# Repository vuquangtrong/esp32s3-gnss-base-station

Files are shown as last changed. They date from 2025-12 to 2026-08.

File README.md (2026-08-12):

# RTK GNSS Base Station using ESP32-S3 and Ublox ZED-F9P

Design and build a RTK GNSS Base Station to provide precise positioning service, which sends RTCM messages over a self-hosted NTRIP web server or an external Radio module, supports micro SD Card storage for post-processing purposes.

This project is developed on top of [ESP32-S3-WROOM-1-N16R8](https://documentation.espressif.com/esp32-s3-wroom-1_wroom-1u_datasheet_en.pdf), with below specifications:

- Xtensa® dual-core 32-bit LX7 microprocessor with single precision FPU, up to 240 MHz
- 384 KB ROM
- 512 KB SRAM + 16 KB SRAM in RTC
- Embedded 8 MB PSRAM (Octal SPI), up to 80 MHz
- Integrated 16 MB Flash (Quad SPI), up to 80 MHz
- 2.4 GHz Wi-Fi (802.11b/g/n, STA/AP/STA+AP, 150 Mbps) and Bluetooth 5 (BLE, Mesh, 2 Mbps)
- SPI, LCD interface, Camera interface, UART, I2C, I2S, remote control, pulse counter, LED PWM, full-speed USB 2.0 OTG, USB Serial/JTAG controller, MCPWM, SD/MMC host controller, GDMA, TWAI® controller (compatible with ISO 11898-1), ADC, touch sensor,temperature sensor, timers and watchdogs
- 36 GPIOs

## Hardware

### Design Tools

Install **KiCad**:

```sh
sudo add-apt-repository ppa:kicad/kicad-9.0-releases
sudo apt update
sudo apt install kicad
```

Extensions:

- Parts from Espressif: <https://github.com/espressif/kicad-libraries>
- Parts from JLCPCB: <https://github.com/CDFER/JLCPCB-Kicad-Library>
- PCB Export to JLCPCB: <https://github.com/Bouni/kicad-jlcpcb-tools>
- PCB RF tools: <https://github.com/easyw/RF-tools-KiCAD>

Parts:

- JLCPCB Parts: <https://jlcpcb.com/parts/> which mainly is from LCSC Parts: <https://www.lcsc.com/>

  - Search for **Stock Type = In Stock** and **Parts Type = Basic | Promotional Extended** and **PCBA Type = Economic**

  - Use `easyeda2kicad` to download symbols, footprints and 3D models from LCSC to KiCAD:

    <details>

    <https://github.com/enduity/easyeda2kicad>>

    Install:

    ``` sh
    cd hardware
    git clone https://github.com/enduity/easyeda2kicad
    cd easyeda2kicad
    python3 -m venv .venv
    source .venv/bin/activate
    pip install .
    ```

    Go back to the hardware project folder, create `libs` folder:

    ```sh
    cd ..
    mkdir -p libs
    ```

    Then download parts from LCSC, for example, ESP32-S3-WROOM-1-N16R8 has LCSCID=C2913202:

    ```sh esp32-s3-gnss-base-station/hardware (.venv)
    easyeda2kicad --lcsc_id C2913202 --full --output ./libs/LCSC --project-relative
    ```

    Add the LCSC libs into KiCAD projects:

    - Goto `Preferences` > `Manage Symbol Libraries`, in Project Specific Libs, add `${KIPRJMOD}/libs/LCSC.kicad_sym`
    - Goto `Preferences` > `Manage Footprint Libraries`, in Project Specific Libs, add `${KIPRJMOD}/libs/LCSC.pretty`

    </details>

### Schematic

**Components**:

| Part | Link |
| --- | --- |
| Espressif WiFi Module ESP32-S3-WROOM-1-N16R8 | <https://jlcpcb.com/partdetail/3198300-ESP32_S3_WROOM_1N16R8/C2913202> |
| U-blox GNSS Receiver ZED-F9P-04B | <https://jlcpcb.com/partdetail/UBLOX-ZED_F9P04B/C5120257> |
| ShouHan Female Micro-B Connector MicroQTJ | <https://jlcpcb.com/partdetail/SHOUHAN-MicroQTJ/C404968> |
| SOFNG MicroSD Card Push-Push Connector TF001B | <https://jlcpcb.com/partdetail/SOFNG-TF001B/C125617> |
| XKB 125V 3A SPDT Slide Switch SS-12D10L5 | <https://jlcpcb.com/partdetail/XKBConnection-SS12D10L5/C319012> |
| SILICON LABS 3.3V 20mA 1Mbps USB 2.0 Transceiver CP2102-GMR | <https://jlcpcb.com/partdetail/SKYWORKS_SILICONLABS-CP2102GMR/C6568> |
| TOPPOWER 4.2V 450mA 1-Cell Lithium Battery Charger TP4054-42-SOT25R | <https://jlcpcb.com/partdetail/33539-TP4054_42SOT25R/C32574> |
| Silergy Corp 2.7-5.5V 2A Adjustable Buck DC Converter SY8089AAAC | <https://jlcpcb.com/partdetail/SilergyCorp-SY8089AAAC/C78988> |
| Hongjiacheng 2-NPN SOT-363 Bipolar MMDT3904 | <https://jlcpcb.com/partdetail/hongjiacheng-MMDT3904/C41375125> |
| JST 1x2P 2mm Connector B2B-PH-K-S(LF)(SN) | <https://jlcpcb.com/partdetail/JST-B2B_PH_K_S_LF_SN/C131337> |
| UNI-ROYAL(Uniroyal Elec) 100mW 33Ω 75V 0603 SMD 0603WAF330JT5E | <https://jlcpcb.com/partdetail/23867-0603WAF330JT5E/C23140> |
| UNI-ROYAL(Uniroyal Elec) 100mW 1kΩ 75V 0603 SMD 0603WAF1001T5E | <https://jlcpcb.com/partdetail/21904-0603WAF1001T5E/C21190> |
| UNI-ROYAL(Uniroyal Elec) 100mW 2.2kΩ 75V 0603 SMD 0603WAF2201T5E | <https://jlcpcb.com/partdetail/4597-0603WAF2201T5E/C4190> |
| UNI-ROYAL(Uniroyal Elec) 100mW 10kΩ 75V 0603 SMD 0603WAF1002T5E | <https://jlcpcb.com/partdetail/26547-0603WAF1002T5E/C25804> |
| UNI-ROYAL(Uniroyal Elec) 100mW 150kΩ 75V 0603 SMD 0603WAF1503T5E | <https://jlcpcb.com/partdetail/23534-0603WAF1503T5E/C22807> |
| UNI-ROYAL(Uniroyal Elec) 100mW 680kΩ 75V 0603 SMD 0603WAF6803T5E | <https://jlcpcb.com/partdetail/26565-0603WAF6803T5E/C25822> |
| Samsung Electro-Mechanics 100nF 16V X7R ±10% 0402 Ceramic Capacitors CL05B104KO5NNNC | <https://jlcpcb.com/partdetail/1877-CL05B104KO5NNNC/C1525> |
| Samsung Electro-Mechanics 10uF 25V X5R ±20% 0603 Ceramic Capacitors CL10A106MA8NRNC  | <https://jlcpcb.com/partdetail/97651-CL10A106MA8NRNC/C96446> |
| Samsung Electro-Mechanics 22uF 25V X5R ±20% 0805 Ceramic Capacitors CL21A226MAQNNNE  | <https://jlcpcb.com/partdetail/46786-CL21A226MAQNNNE/C45783> |
| Samsung Electro-Mechanics 47pF 50V C0G ±5% 0603 Ceramic Capacitors CL10C470JB8NNNC | <https://jlcpcb.com/partdetail/2023-CL10C470JB8NNNC/C1671> |
| Hubei KENTO Elec 2.4V 20mA 300mcd 40mW 645nm Red Water Clear 0603 LED | <https://jlcpcb.com/partdetail/Hubei_KENTOElec-KT0603R/C2286> |
| Sunlord 2.2uH 2A 52mΩ ±20% SMD 4x4mm Power Inductors SWPA4026S2R2MT | <https://jlcpcb.com/partdetail/Sunlord-SWPA4026S2R2MT/C96891> |
| Murata Electronics 110mA 120nH 2.66Ω ±5% 0402 Power Inductors LQW15ANR12J00D | <https://jlcpcb.com/partdetail/MurataElectronics-LQW15ANR12J00D/C113123> |
| Q&J CR1220 SMD Button And Strip Battery Connector CR1220-2 | <https://jlcpcb.com/partdetail/QJ-CR12202/C70381> |
| BAT WIRELESS 50Ω 6GHz SMB Female Connectors BWSMB-KE | <https://jlcpcb.com/partdetail/BATWIRELESS-BWSMBKE/C5250063> |

**Schematic**

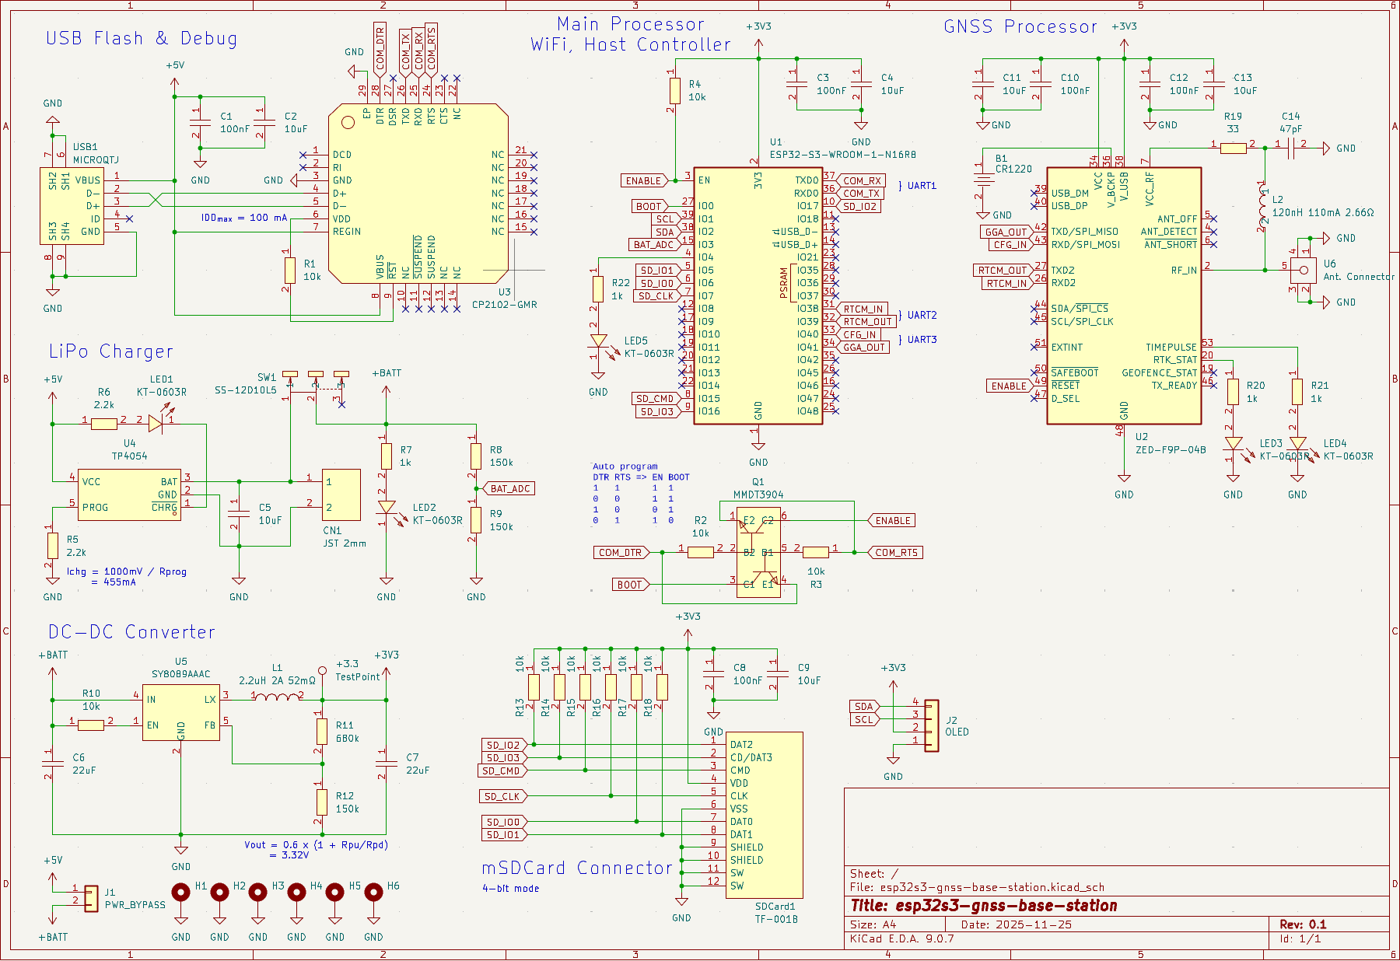
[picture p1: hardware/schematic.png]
Schematic


### PCB Layout

Layers:

- Front Copper: Signal
- Inner 1: GND
- Inner 2: GND
- Back Copper: Signal

RF Path:

- In ZED-F9P Integration manual, it mentions that RF input should ensure RF trace is tuned for 50 Ω to ensure adequate bandwidth and power matching
- Board will be made by JLCPCB, refer their guidance at <https://jlcpcb.com/help/article/User-Guide-to-the-JLCPCB-Impedance-Calculator> to get the trace width, details in [RF Impedance Calculator](hardware/impedance_calculator.png)

PCB Layout:

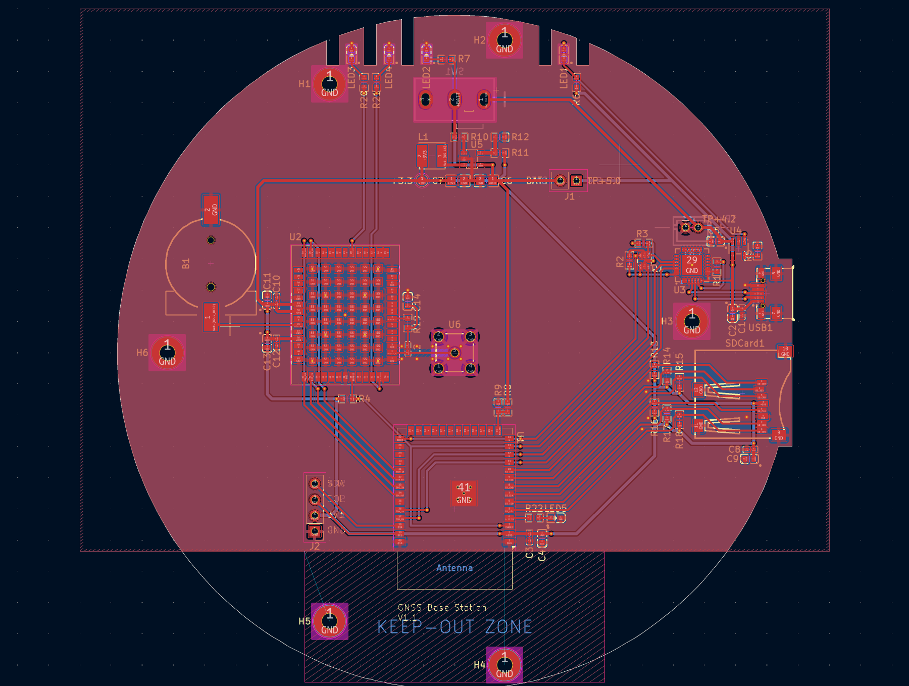
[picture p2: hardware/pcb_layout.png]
Layout


The rendered images:

<div style="display: flex; gap: 16px;">
  <div style="flex: 1;">
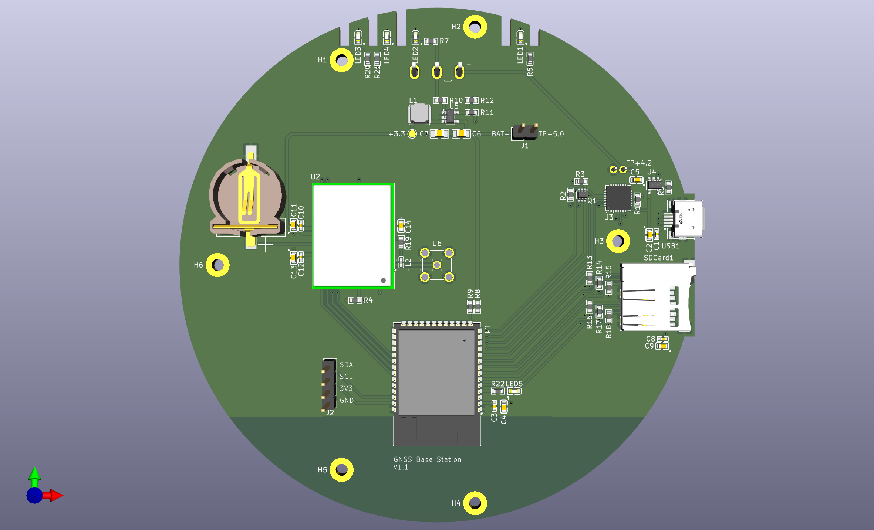
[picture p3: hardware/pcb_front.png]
    
  </div>
  <div style="flex: 1;">
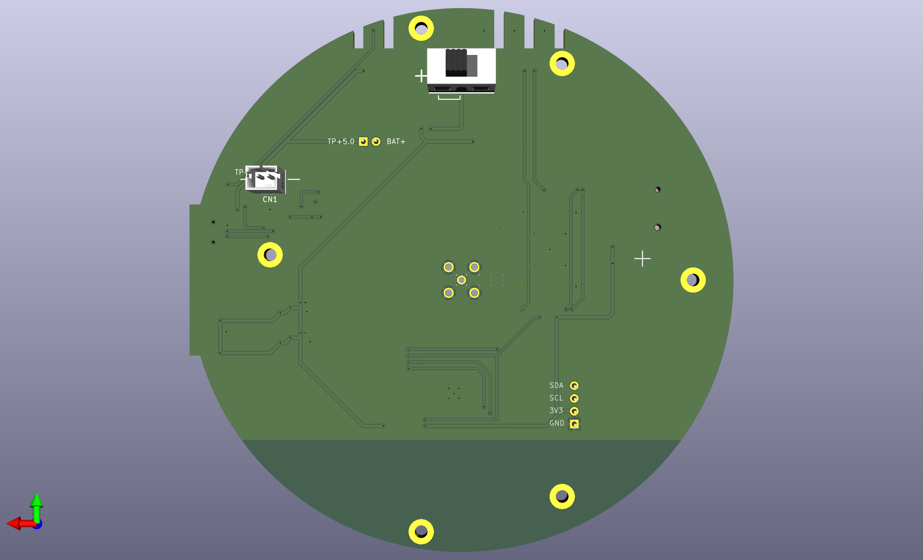
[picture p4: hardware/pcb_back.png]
    
  </div>
</div>

The final board:

<div style="display: flex; gap: 16px;">
  <div style="flex: 1;">
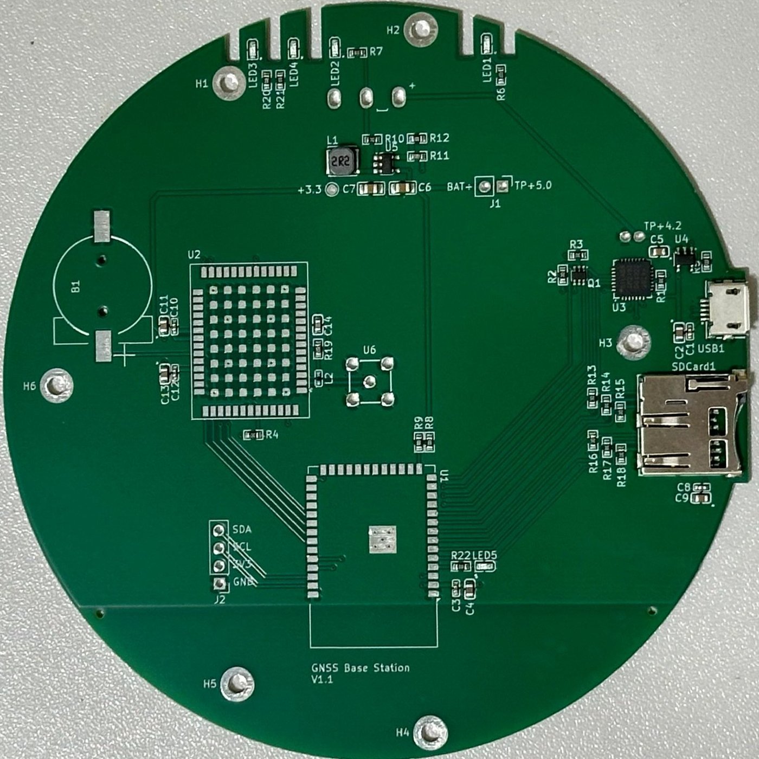
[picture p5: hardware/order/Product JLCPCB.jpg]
    
  </div>
  <div style="flex: 1;">
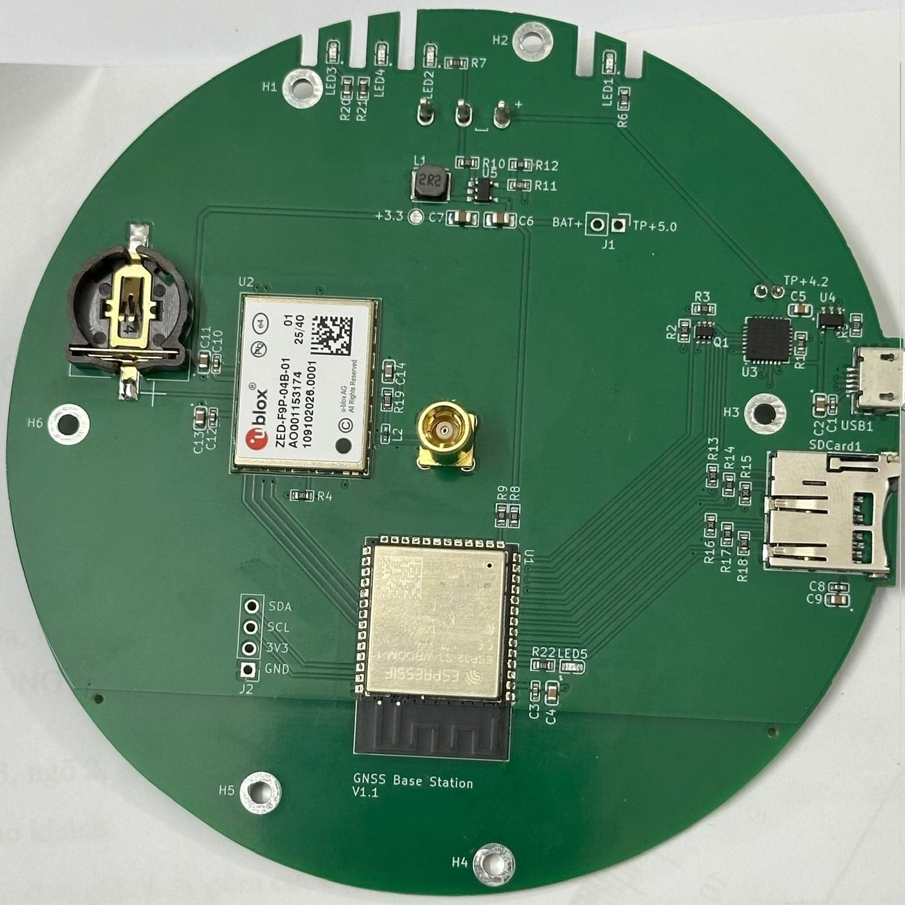
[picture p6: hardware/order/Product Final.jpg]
    
  </div>
</div>

------------------------------------------------------------

## Firmware

### Development Tools

- IDE: Visual Studio Code + ESP-IDF Extenstion
- Framework: ESP-IDF for ESP32-S3

### ESP-IDF

Install EIM:

``` sh
echo "deb [trusted=yes] https://dl.espressif.com/dl/eim/apt/ stable main" | sudo tee /etc/apt/sources.list.d/espressif.list
sudo apt update
sudo apt install eim
```

Install ESP-IDF SDK from EIM:

- Install latest STABLE version, at the moment, it is 6.0.2. The online document for ESP32-S3 is at <https://docs.espressif.com/projects/esp-idf/en/v6.0.2/esp32s3/index.html>
- Use default settings

Add OpenOCD udev rules:

``` sh
find ~/.espressif -type f -name "*.rules" -exec sudo cp -v {} /etc/udev/rules.d/ \;
sudo udevadm control --reload-rules
sudo udevadm trigger
```

### SDK Config

``` ini
CONFIG_IDF_TARGET="esp32s3"
CONFIG_BOOTLOADER_LOG_LEVEL_NONE=y
CONFIG_ESPTOOLPY_FLASHMODE_QIO=y
CONFIG_ESPTOOLPY_FLASHSIZE_16MB=y
CONFIG_COMPILER_OPTIMIZATION_PERF=y
CONFIG_ESP_DEFAULT_CPU_FREQ_MHZ_240=y
CONFIG_ESP32S3_INSTRUCTION_CACHE_32KB=y
CONFIG_ESP32S3_INSTRUCTION_CACHE_LINE_32B=y
CONFIG_ESP32S3_DATA_CACHE_64KB=y
CONFIG_ESP32S3_DATA_CACHE_LINE_64B=y
CONFIG_FREERTOS_GENERATE_RUN_TIME_STATS=y
CONFIG_LOG_DYNAMIC_LEVEL_CONTROL=n
CONFIG_LOG_TAG_LEVEL_IMPL_NONE=y
```

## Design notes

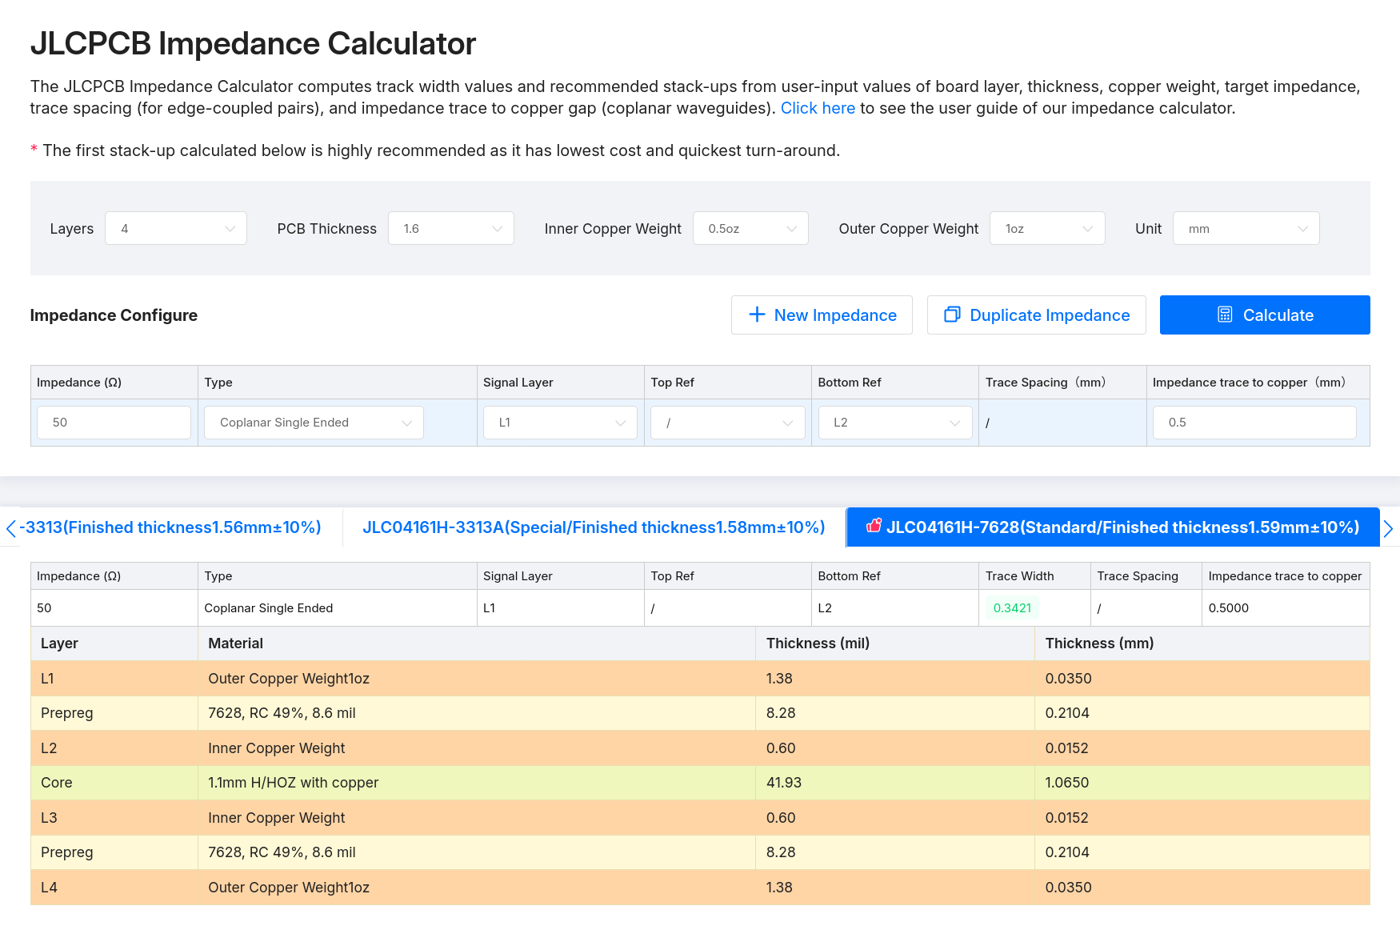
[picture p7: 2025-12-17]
hardware/impedance_calculator.png

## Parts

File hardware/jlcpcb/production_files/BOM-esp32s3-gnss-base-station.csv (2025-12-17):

Comment | Designator | Footprint | LCSC | Quantity
100nF | C1,C10,C12,C3,C8 | C0402 | C1525 | 5
10k | R1,R10,R13,R14,R15,R16,R17,R18,R2,R3,R4 | R0603 | C25804 | 11
10uF | C11,C13,C2,C4,C5,C9 | C0603 | C96446 | 6
120nH 110mA 2.66Ω | L2 | L0402 | C113123 | 1
150k | R12,R8,R9 | R0603 | C22807 | 3
1k | R20,R21,R22,R7 | R0603 | C21190 | 4
2.2k | R5,R6 | R0603 | C4190 | 2
2.2uH 2A 52mΩ | L1 | IND-SMD_L4.0-W4.0 | C96891 | 1
22uF | C6,C7 | C0805 | C45783 | 2
33 | R19 | R0603 | C23140 | 1
47pF | C14 | C0603 | C1671 | 1
680k | R11 | R0603 | C25822 | 1
CP2102-GMR | U3 | WQFN-28_L5.0-W5.0-P0.50-BL-EP3.2 | C6568 | 1
KT-0603R | LED1,LED2,LED3,LED4,LED5 | LED0603-RD | C2286 | 5
MICROQTJ | USB1 | MICRO-USB-SMD_MICROQTJ-5P | C404968 | 1
MMDT3904 | Q1 | SOT-363_L2.0-W1.3-P0.65-LS2.1-BR | C41375125 | 1
SY8089AAAC | U5 | SOT-23-5_L3.0-W1.7-P0.95-LS2.8-BR | C78988 | 1
TF-001B | SDCard1 | TF-SMD_TF-001B | C125617 | 1
TP4054 | U4 | SOT-23-5_L3.0-W1.7-P0.95-LS2.8-BL | C32574 | 1

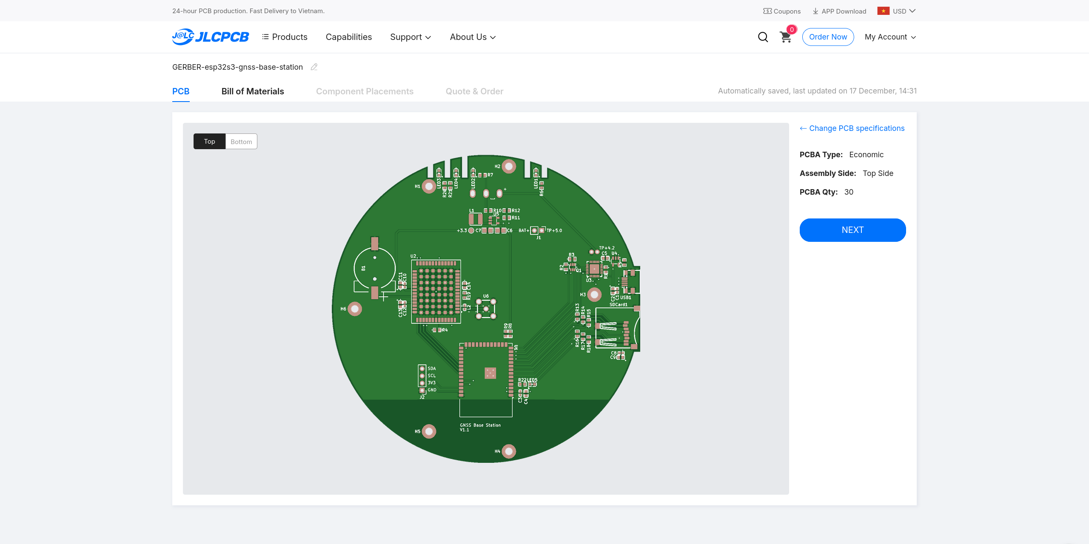
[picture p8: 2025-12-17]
hardware/order/Screenshot 2025-12-17 at 14-31-33 PCB Preview - JLCPCB.png

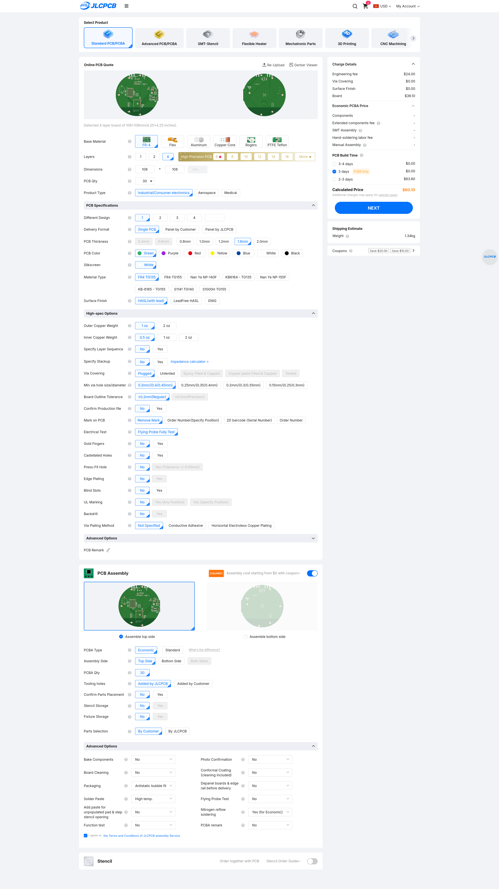
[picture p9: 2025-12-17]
hardware/order/Screenshot 2025-12-17 at 14-31-19 PCB Instant Quote - JLCPCB.png

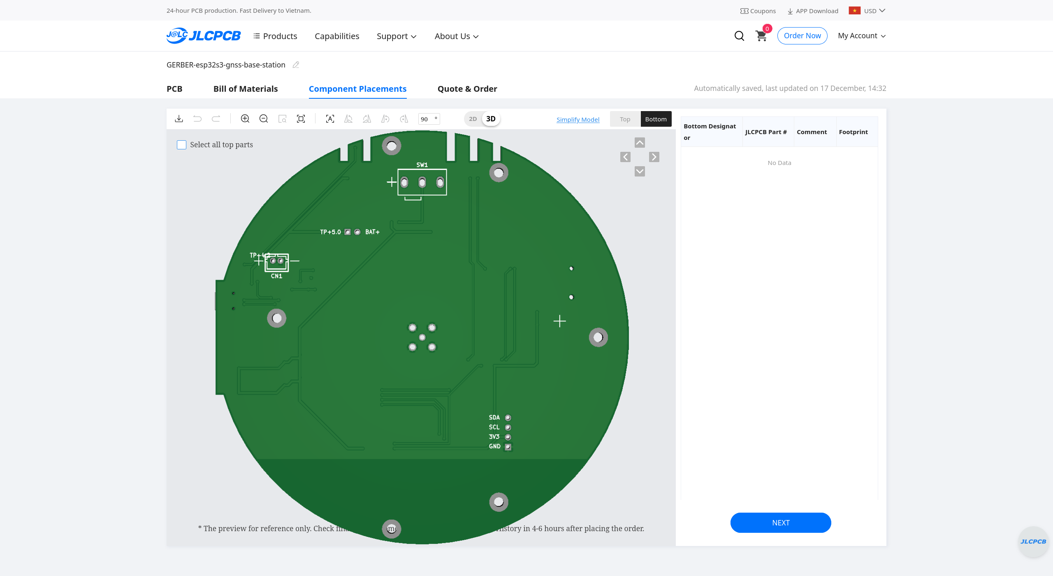
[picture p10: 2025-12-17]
hardware/order/Screenshot 2025-12-17 at 14-34-23 CPL Preview - JLCPCB.png

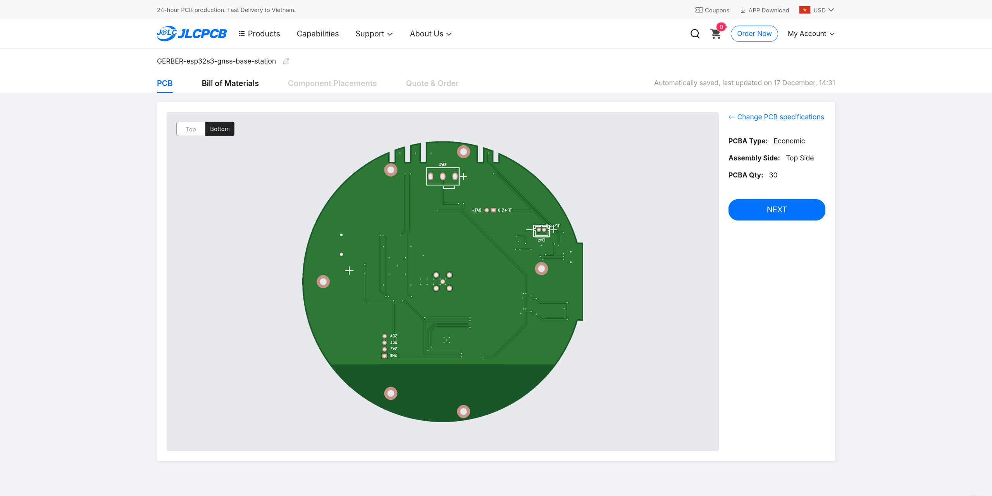
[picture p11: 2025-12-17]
hardware/order/Screenshot 2025-12-17 at 14-31-39 PCB Preview - JLCPCB.png

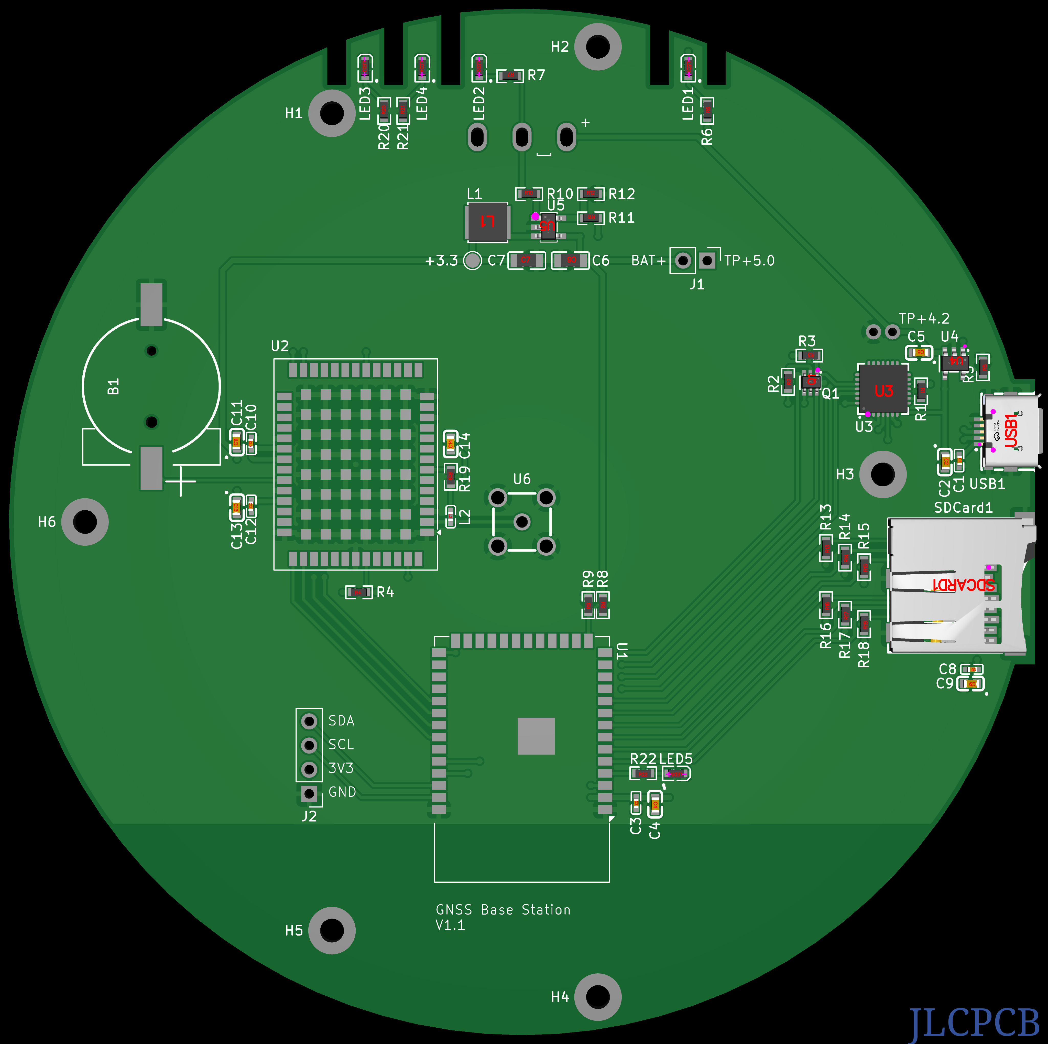
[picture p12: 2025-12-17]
hardware/order/Screenshot 2025-12-17 at 14-33-52 CPL Preview - JLCPCB.jpeg

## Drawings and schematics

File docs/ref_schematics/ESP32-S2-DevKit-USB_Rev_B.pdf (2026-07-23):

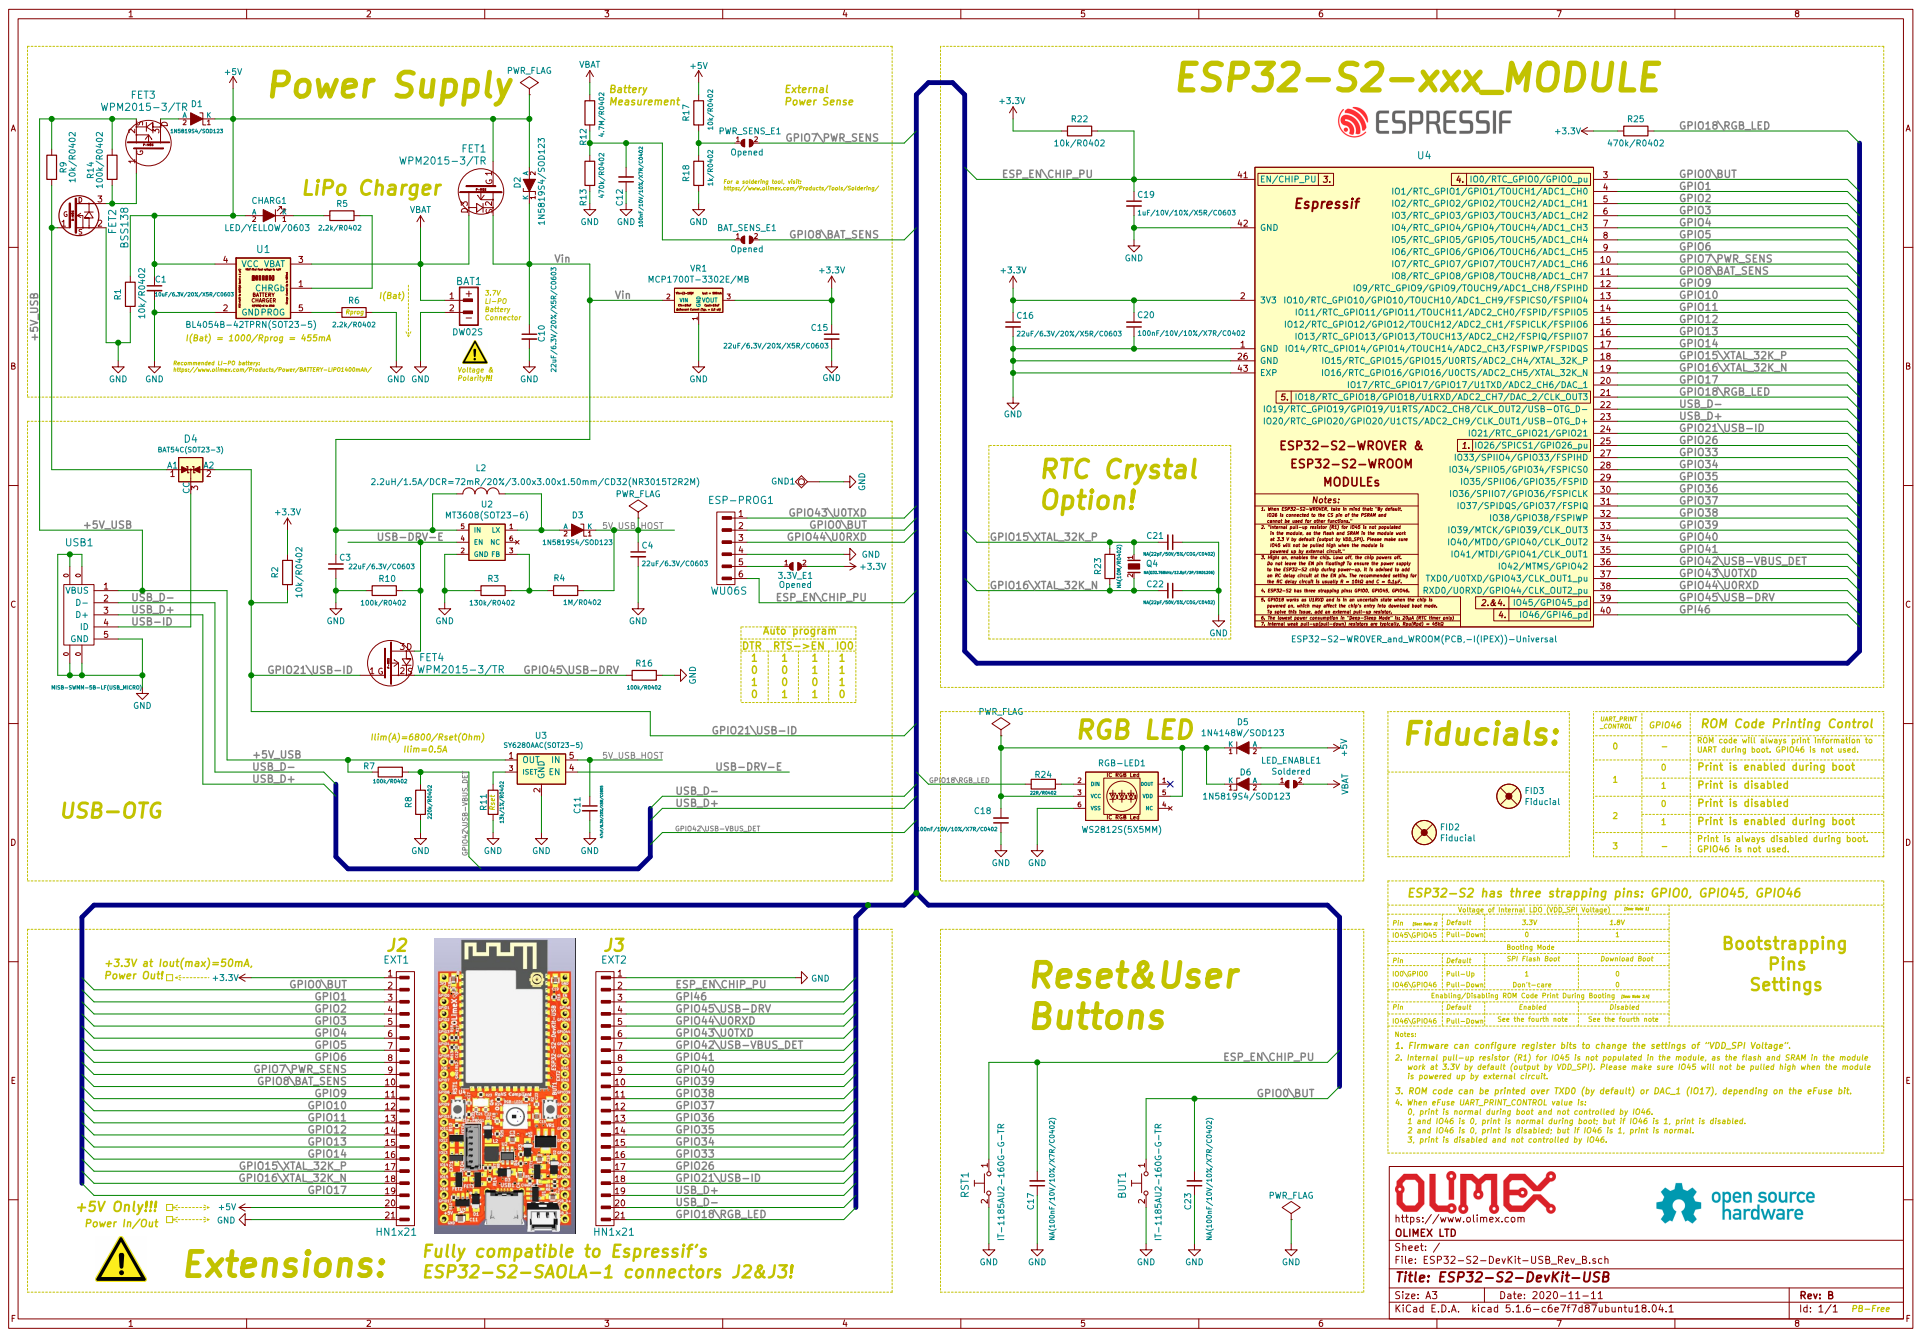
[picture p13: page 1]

Booting Mode LiPo Charger

For a soldering tool, visit: https://www.olimex.com/Products/Tools/Soldering/

1 2 Q4 R23 NA(Q32.768kHz/12.5pF/2P/SMD1206) NA(10M/R0402) Charge Current Up to 800mA R(PROG)=2 to 10k VBAT final float voltage to 4.2V VCC=4.5V to 6.5V(at least a 1 F) BATTERY CHARGER CHRGb 1 GND 2 VBAT 3 VCC 4 PROG 5 U1

to the ESP32-S2 chip during power-up, it is advised to add GND 1

Recommended LI-PO battery: https://www.olimex.com/Products/Power/BATTERY-LIPO1400mAh/

4. ESP32-S2 has three strapping pins: GPIO0, GPIO45, GPIO46. 5.

GPIO21\USB-ID GPIO41 GPIO21\USB-ID GPIO40

cannot be used for other functions." Do not leave the EN pin floating! To ensure the power supply ESP32-S2-WROOM

IO45 will not be pulled high when the module is MODULEs

IO26 is connected to the CS pin of the PSRAM and

in the module, as the flash and SRAM in the module work
5. GPIO18 works as U1RXD and is in an uncertain state when the chip is 6. The lowest power consumption in "Deep-Sleep Mode" is: 20A (RTC timer only) 7. Internal weak pull-up(pull-down) resistors are typically, Rpu(Rpd) = 45k an RC delay circuit at the EN pin. The recommended setting for at 3.3 V by default (output by VDD_SPI). Please make sure

powered on, which may affect the chips entry into download boot mode. powered up by external circuit."
3. High: on, enables the chip. Low: off, the chip powers off.

the RC delay circuit is usually R = 10k and C = 0.1F. To solve this issue, add an external pull-up resistor.

See the fourth note RGB LED

Ilim(A)=6800/Rset(Ohm)
- Fully compatible to Espressif's
Ilim=0.5A

0 Print is disabled Print is disabled

is powered up by external circuit. 1. Firmware can configure register bits to change the settings of VDD_SPI Voltage. Notes: ESP32-S2 has three strapping pins: GPIO0, GPIO45, GPIO46

3, print is disabled and not controlled by IO46. 3. ROM code can be printed over TXD0 (by default) or DAC_1 (IO17), depending on the eFuse bit. 2. Internal pull-up resistor (R1) for IO45 is not populated in the module, as the flash and SRAM in the module
work at 3.3V by default (output by VDD_SPI). Please make sure IO45 will not be pulled high when the module

0, print is normal during boot and not controlled by IO46.
1 and IO46 is 0, print is normal during boot; but if IO46 is 1, print is disabled.
2 and IO46 is 0, print is disabled; but if IO46 is 1, print is normal.

1 2BUT1 IT-1185AU2-160G-G-TR GND GND

File: ESP32-S2-DevKit-USB_Rev_B.sch Sheet: / OLIMEX LTD

Id: 1/1 Title: ESP32-S2-DevKit-USB

Rev: B | F Date: 2020-11-11 KiCad E.D.A. kicad 5.1.6-c6e7f7d87ubuntu18.04.1 Size: A3

PB-Free

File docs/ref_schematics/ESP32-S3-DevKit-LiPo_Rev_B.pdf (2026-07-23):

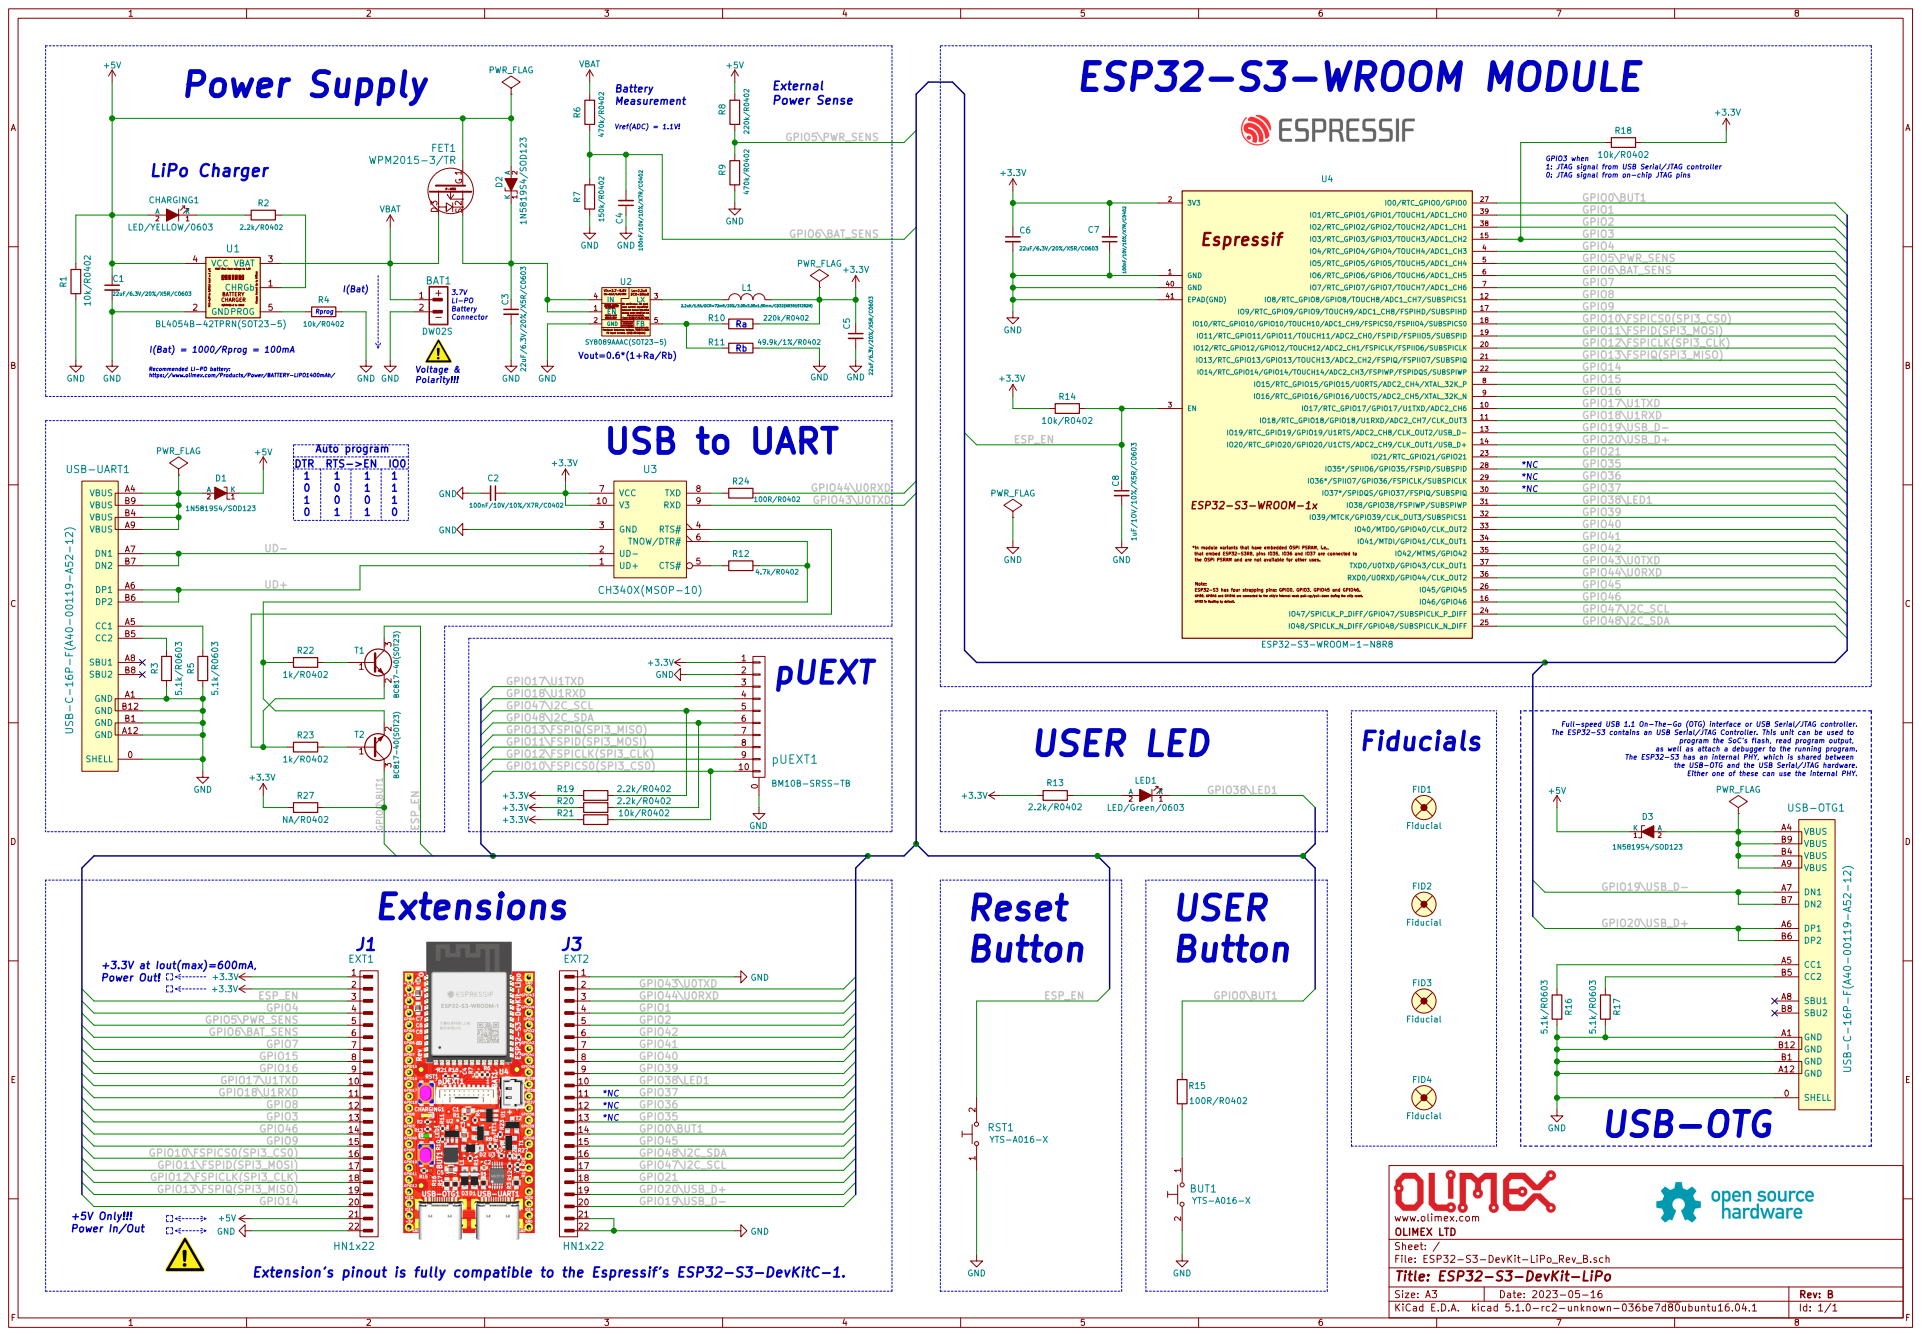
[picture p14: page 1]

External
Power Sense
the OSPI PSRAM and are not available for other uses. GND 1

10k/R0402 GPIO3 when 1: JTAG signal from USB Serial/JTAG controller 0: JTAG signal from on-chip JTAG pins

Full-speed USB 1.1 On-The-Go (OTG) interface or USB Serial/JTAG controller. The ESP32-S3 contains an USB Serial/JTAG Controller. This unit can be used to program the SoCs flash, read program output, as well as attach a debugger to the running program. The ESP32-S3 has an internal PHY, which is shared between the USB-OTG and the USB Serial/JTAG hardware. Either one of these can use the internal PHY. GPIO6\BAT_SENS

load current capability! Lx=2.2uH

Do not float. Enable control. FB Input Current, I(FB)=50nA(max) Feedback Reference Voltage, V(REF)=0.6V

*In module variants that have embedded OSPI PSRAM, i.e., ESP32-S3 has four strapping pins: GPIO0, GPIO3, GPIO45 and GPIO46. ESP32-S3-WROOM-1x

that embed ESP32-S3R8, pins IO35, IO36 and IO37 are connected to

GPIO0, GPIO45 and GPIO46 are connected to the chips internal weak pull-up/pull-down during the chip reset. GPIO3 is floating by default. Note:

9EXT1 HN1x22 Extension's pinout is fully compatible to the Espressif's ESP32-S3-DevKitC-1.
+3.3V GND
ESP_EN GPIO4 GPIO5\PWR_SENS

www.olimex.com
File: ESP32-S3-DevKit-LiPo_Rev_B.sch Sheet: / OLIMEX LTD

Id: 1/1 Title: ESP32-S3-DevKit-LiPo

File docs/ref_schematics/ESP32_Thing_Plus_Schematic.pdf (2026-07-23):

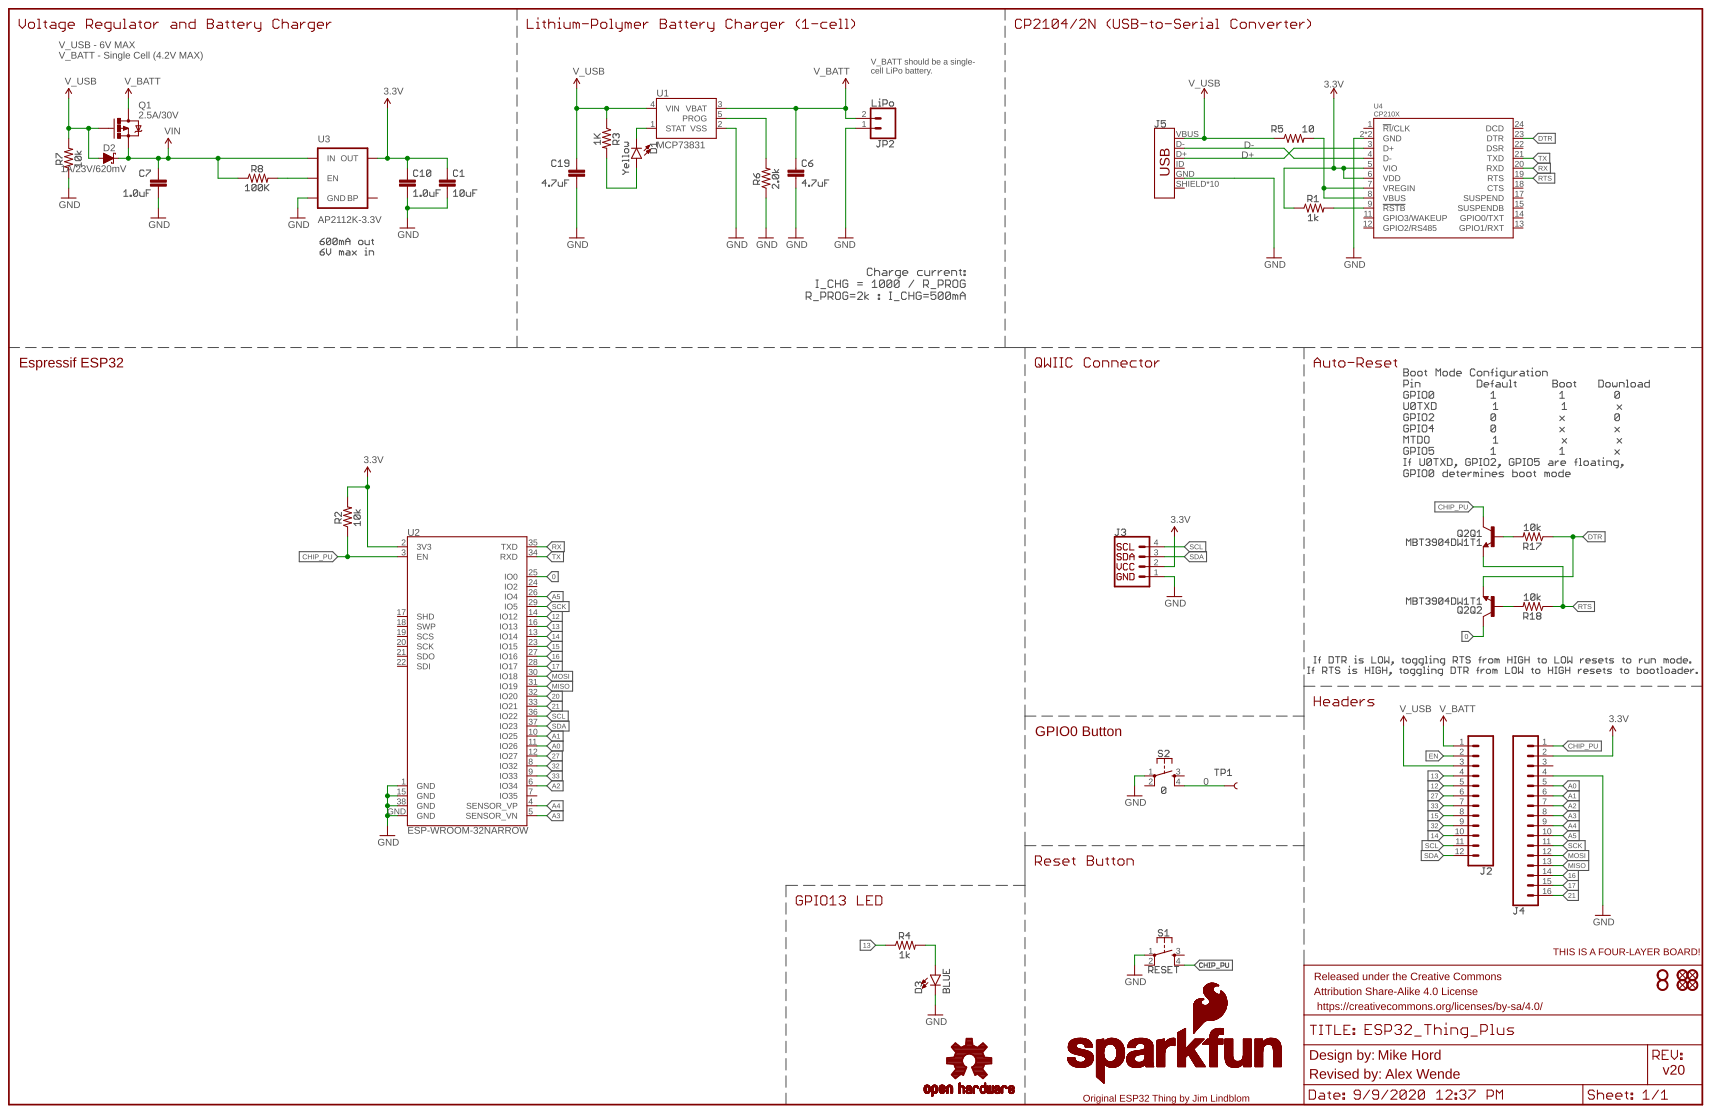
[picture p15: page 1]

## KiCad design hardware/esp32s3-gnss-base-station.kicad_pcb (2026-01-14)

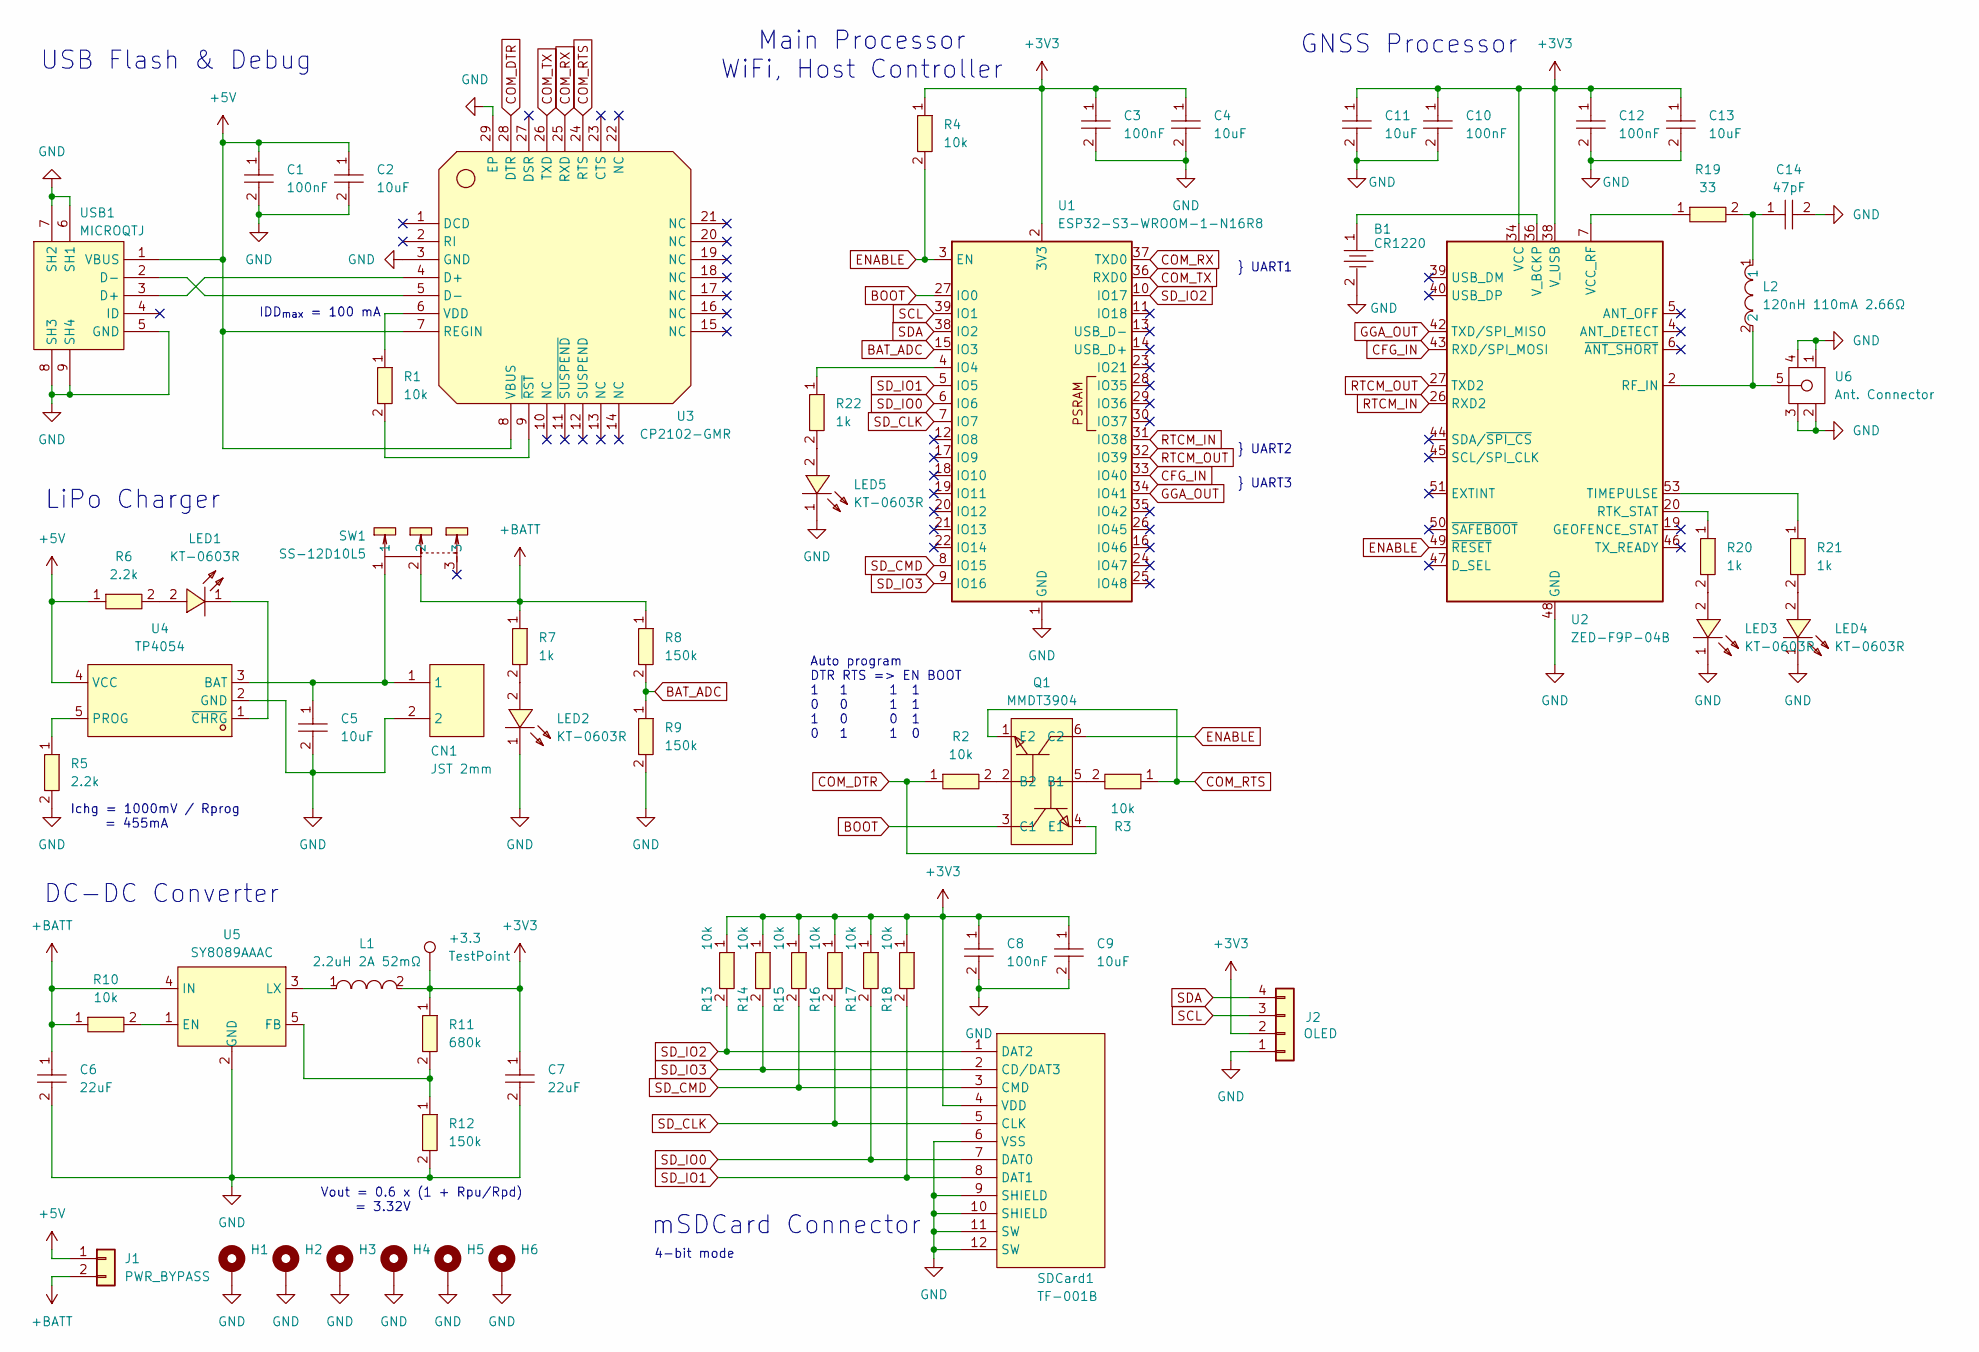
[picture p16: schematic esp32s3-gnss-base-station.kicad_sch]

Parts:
+3.3: TestPoint; TestPoint_Pad_D1.5mm
B1: CR1220; BAT-SMD_CR1220-2; LCSC Part C70381
C1, C3, C8, C10, C12: 100nF; C0402; LCSC Part C1525
C2, C4, C5, C9, C11, C13: 10uF; C0603; LCSC Part C96446
C6, C7: 22uF; C0805; LCSC Part C45783
C14: 47pF; C0603; LCSC Part C1671
CN1: JST 2mm; CONN-TH_B2B-PH-K-S; LCSC Part C131337
H1, H2, H3, H4, H5, H6: MountingHole_Pad; MountingHole_2.5mm_Pad
J1: PWR_BYPASS; PinHeader_1x02_P2.54mm_Vertical
J2: OLED; PinHeader_1x04_P2.54mm_Vertical
L1: 2.2uH 2A 52mΩ; IND-SMD_L4.0-W4.0; LCSC Part C96891
L2: 120nH 110mA 2.66Ω; L0402; LCSC Part C113123
LED1, LED2, LED3, LED4, LED5: KT-0603R; LED0603-RD; LCSC Part C2286
Q1: MMDT3904; SOT-363_L2.0-W1.3-P0.65-LS2.1-BR; LCSC Part C41375125
R1, R2, R3, R4, R10, R13, R14, R15, R16, R17, R18: 10k; R0603; LCSC Part C25804
R5, R6: 2.2k; R0603; LCSC Part C4190
R7, R20, R21, R22: 1k; R0603; LCSC Part C21190
R8, R9, R12: 150k; R0603; LCSC Part C22807
R11: 680k; R0603; LCSC Part C25822
R19: 33; R0603; LCSC Part C23140
SDCard1: TF-001B; TF-SMD_TF-001B; LCSC Part C125617
SW1: SS-12D10L5; SW-TH_SS-12D10L5; LCSC Part C319012
U1: ESP32-S3-WROOM-1-N16R8; ESP32-S3-WROOM-1
U2: ZED-F9P-04B; ublox_ZED
U3: CP2102-GMR; WQFN-28_L5.0-W5.0-P0.50-BL-EP3.2; LCSC Part C6568
U4: TP4054; SOT-23-5_L3.0-W1.7-P0.95-LS2.8-BL; LCSC Part C32574
U5: SY8089AAAC; SOT-23-5_L3.0-W1.7-P0.95-LS2.8-BR; LCSC Part C78988
U6: Ant. Connector; SMA-TH_BWMCX-KE; LCSC Part C5137197
USB1: MICROQTJ; MICRO-USB-SMD_MICROQTJ-5P; LCSC Part C404968

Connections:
+3V3: +3.3.1, C3.1, C4.1, C7.1, C8.1, C9.1, C10.1, C11.1, C12.1, C13.1, J2.2, L1.2, R4.1, R11.1, R13.1, R14.1, R15.1, R16.1, R17.1, R18.1, SDCard1.4 (VDD), U1.2 (3V3), U2.33 (VCC), U2.34 (VCC), U2.38 (V_USB)
+5V: C1.1, C2.1, J1.1, R6.1, U3.7 (REGIN), U3.8 (VBUS), U4.4 (VCC), USB1.1 (VBUS)
+BATT: C6.1, J1.2, R7.1, R8.1, R10.1, SW1.2, U5.4 (IN)
BAT_ADC: R8.2, R9.1, U1.15 (IO3)
BOOT: Q1.3 (C1), U1.27 (IO0)
CFG_IN: U1.33 (IO40), U2.43 (RXD/SPI_MOSI)
COM_DTR: Q1.4 (E1), R2.1, U3.28 (DTR)
COM_RTS: Q1.1 (E2), R3.1, U3.24 (RTS)
COM_RX: U1.37 (TXD0), U3.25 (RXD)
COM_TX: U1.36 (RXD0), U3.26 (TXD)
ENABLE: Q1.6 (C2), R4.2, U1.3 (EN), U2.49 (~RESET)
GGA_OUT: U1.34 (IO41), U2.42 (TXD/SPI_MISO)
GND: B1.2, C1.2, C2.2, C3.2, C4.2, C5.2, C6.2, C7.2, C8.2, C9.2, C10.2, C11.2, C12.2, C13.2, C14.2, CN1.2, H1.1, H2.1, H3.1, H4.1, H5.1, H6.1, J2.1, LED2.1, LED3.1, LED4.1, LED5.1, R5.2, R9.2, R12.2, SDCard1.6 (VSS), SDCard1.9 (SHIELD), SDCard1.10 (SHIELD), SDCard1.11 (SW), SDCard1.12 (SW), U1.1 (GND), U1.40 (GND), U1.41 (GND), U2.1 (GND), U2.3 (GND), U2.12 (GND), U2.14 (GND), U2.32 (GND), U2.37 (GND), U2.41 (GND), U2.48 (GND), U2.55 (GND), U3.3 (GND), U3.29 (EP), U4.2 (GND), U5.2 (GND), U6.1, U6.2, U6.3, U6.4, USB1.5 (GND), USB1.6 (SH1), USB1.7 (SH2), USB1.8 (SH3), USB1.9 (SH4)
unnamed: C14.1, L2.1, R19.2
unnamed: LED1.2, R6.2
unnamed: LED2.2, R7.2
unnamed: LED3.2, R20.2
unnamed: LED4.2, R21.2
unnamed: LED5.2, R22.2
unnamed: Q1.5 (B1), R3.2
unnamed: Q1.2 (B2), R2.2
unnamed: R22.1, U1.4 (IO4)
unnamed: L2.2, U2.2 (RF_IN), U6.5
unnamed: R20.1, U2.20 (RTK_STAT)
unnamed: R21.1, U2.53 (TIMEPULSE)
unnamed: R19.1, U2.7 (VCC_RF)
unnamed: B1.1, U2.36 (V_BCKP)
unnamed: U3.4 (D+), USB1.3 (D+)
unnamed: U3.5 (D-), USB1.2 (D-)
unnamed: R1.1, U3.6 (VDD)
unnamed: R1.2, U3.9 (~RST)
unnamed: C5.1, CN1.1, SW1.1, U4.3 (BAT)
unnamed: R5.1, U4.5 (PROG)
unnamed: LED1.1, U4.1 (~CHRG)
unnamed: R10.2, U5.1 (EN)
unnamed: R11.2, R12.1, U5.5 (FB)
unnamed: L1.1, U5.3 (LX)
RTCM_IN: U1.31 (IO38), U2.26 (RXD2)
RTCM_OUT: U1.32 (IO39), U2.27 (TXD2)
SCL: J2.3, U1.39 (IO1)
SDA: J2.4, U1.38 (IO2)
SD_CLK: R16.2, SDCard1.5 (CLK), U1.7 (IO7)
SD_CMD: R15.2, SDCard1.3 (CMD), U1.8 (IO15)
SD_IO0: R17.2, SDCard1.7 (DAT0), U1.6 (IO6)
SD_IO1: R18.2, SDCard1.8 (DAT1), U1.5 (IO5)
SD_IO2: R13.2, SDCard1.1 (DAT2), U1.10 (IO17)
SD_IO3: R14.2, SDCard1.2 (CD/DAT3), U1.9 (IO16)

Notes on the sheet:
Ichg = 1000mV / Rprog = 455mA
Vout = 0.6 x (1 + Rpu/Rpd) = 3.32V
Auto program DTR RTS => EN BOOT 1 1 1 1 0 0 1 1 1 0 0 1 0 1 1 0
LiPo Charger
} UART1
} UART3
} UART2
4-bit mode
Main Processor WiFi, Host Controller
USB Flash & Debug
DC-DC Converter
mSDCard Connector
IDD_{max} = 100 mA
GNSS Processor

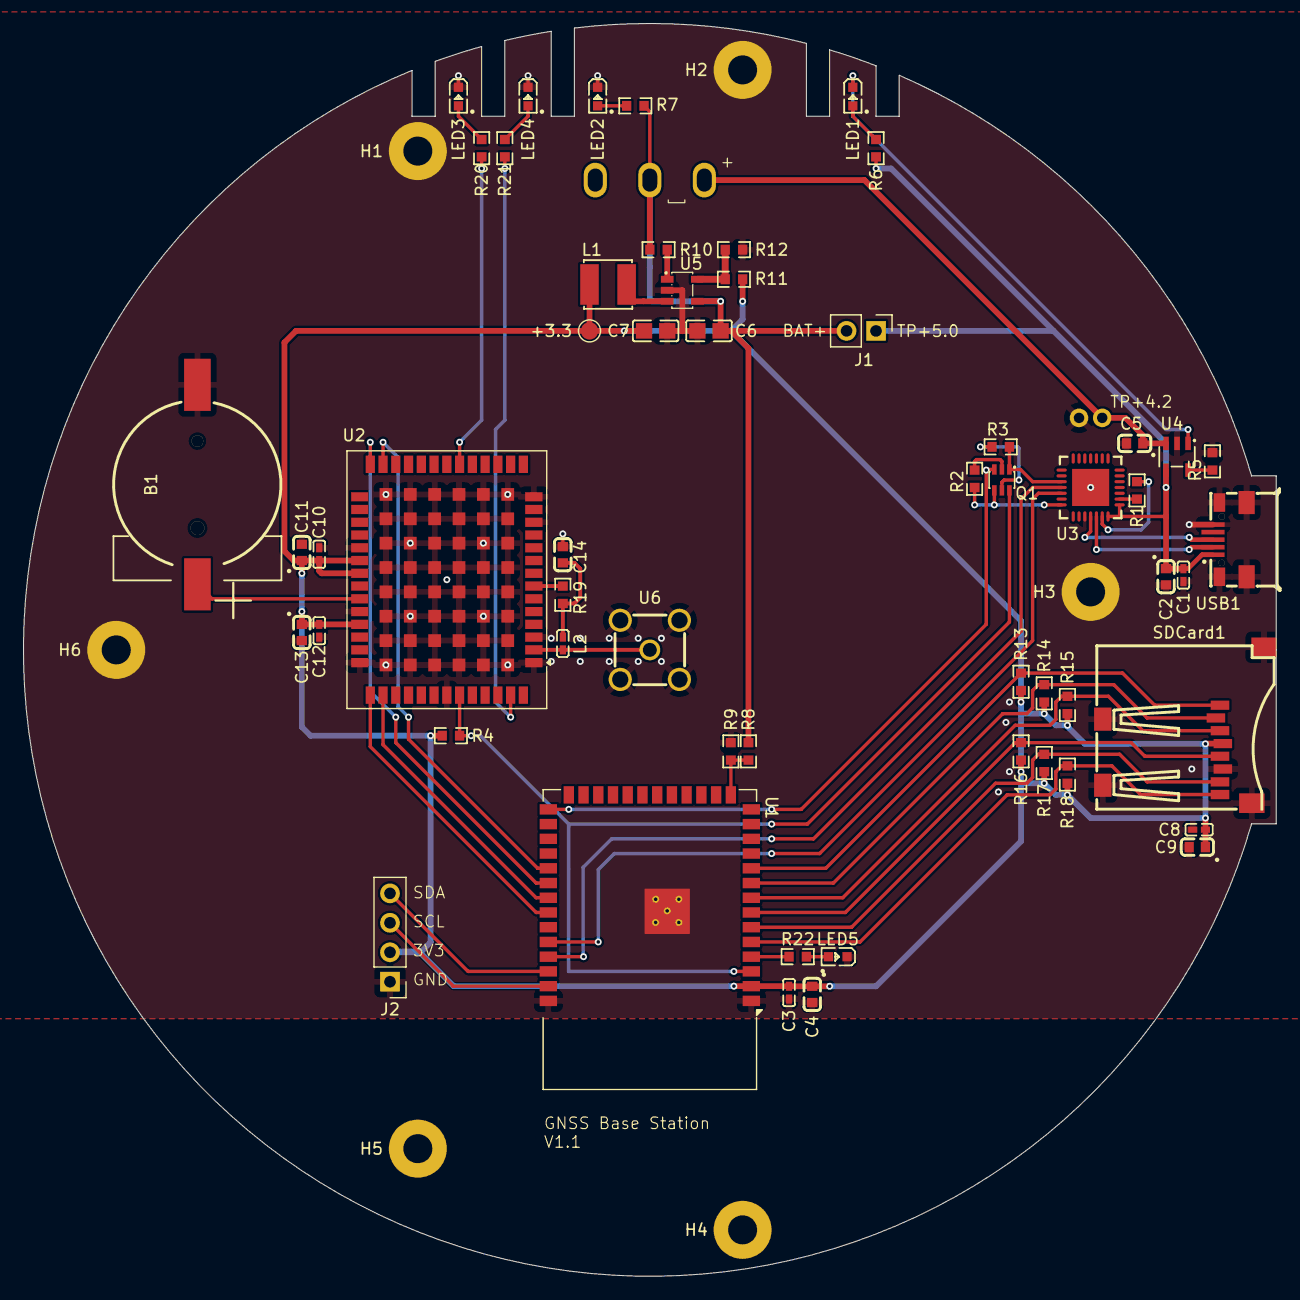
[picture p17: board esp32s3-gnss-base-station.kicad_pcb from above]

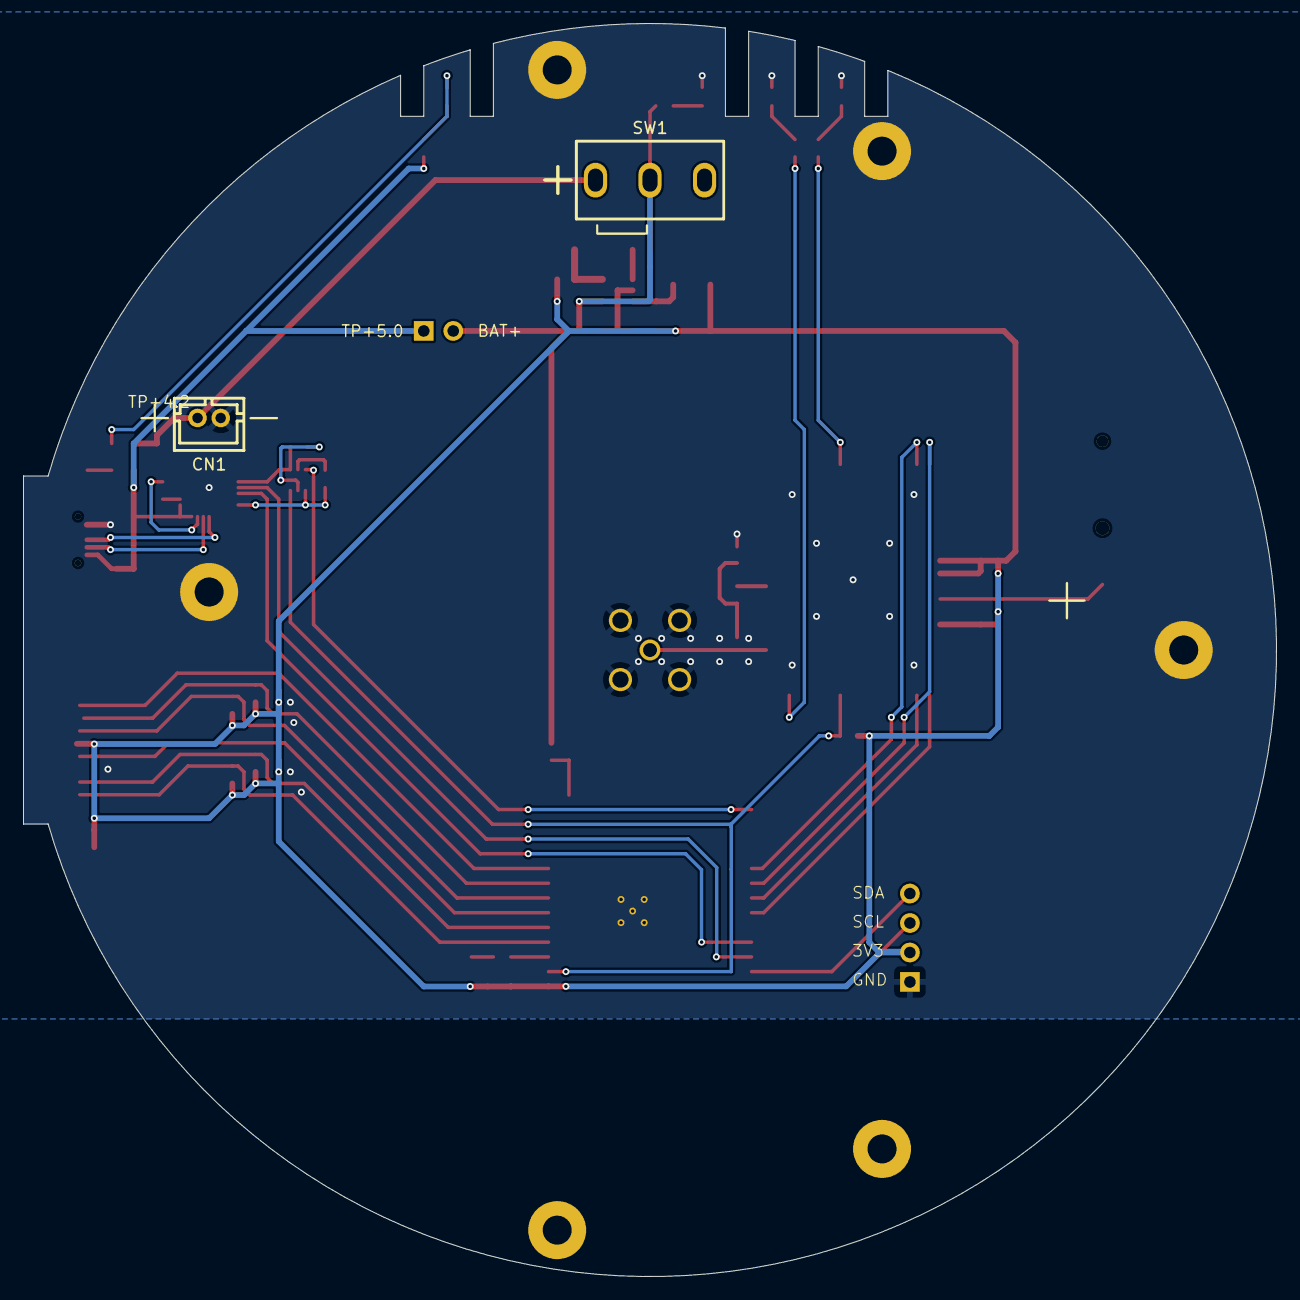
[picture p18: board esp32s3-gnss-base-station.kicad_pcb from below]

Board: 4 copper layers, 108.0 x 108.0 mm, 64 parts (2 on the bottom side), 47 nets.

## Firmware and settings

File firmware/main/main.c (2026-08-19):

#include <stdio.h>

// #include "esp_timer.h"
#include "battery.h"
#include "config.h"
#include "freertos/FreeRTOS.h"
#include "freertos/task.h"
#include "gnss.h"
#include "parser.h"
#include "sdcard.h"
#include "server.h"
#include "status.h"
#include "storage.h"
#include "uart.h"
#include "wifi.h"

#if 0

static void monitor_task(void* args)
{
    char* stats_buffer = malloc(1024);
    if (stats_buffer == NULL)
    {
        printf("Failed to allocate memory for stats buffer!\n");
        vTaskDelete(NULL);
        return;
    }

    while (1)
    {
        // Calculate uptime timestamp in seconds
        // int64_t time_us = esp_timer_get_time();
        // uint32_t sec = (uint32_t)(time_us / 1000000ULL);
        // printf("\n[%lu s] SYSTEM STATISTICS REPORT\n", sec);

        // Print Task List (Name, State, Priority, Stack High Water Mark, Task Number)
        // Note: Stack High Water Mark is given in bytes on ESP-IDF FreeRTOS.
        printf("\nName          State   Prio    StackFree TaskID\n");
        vTaskList(stats_buffer);
        printf("%s", stats_buffer);

        // Print CPU Run Time Statistics
        printf("\nTask Name     Abs Time        %% Time\n");
        vTaskGetRunTimeStats(stats_buffer);
        printf("%s", stats_buffer);

        // Print Free Heap Size
        printf("\nHeapFree: %lu B\n", (unsigned long)esp_get_free_heap_size());

        // Delay before refreshing statistics
        vTaskDelay(pdMS_TO_TICKS(10000));
    }

    // Cleanup (though loop runs infinitely)
    free(stats_buffer);
}
#endif

void app_main(void)
{
    printf("\nV" VERSION " " GIT_COMMIT " " BUILD_TIME "\n");

    ESP_ERROR_CHECK(config_init());
    ESP_ERROR_CHECK(storage_init());
    ESP_ERROR_CHECK(battery_init());
    ESP_ERROR_CHECK(wifi_init());
    ESP_ERROR_CHECK(uart_init());
    ESP_ERROR_CHECK(sdcard_init());

    gnss_set_mode_rover();

    ESP_ERROR_CHECK(parser_init());
    ESP_ERROR_CHECK(server_init());

#if 0
    // Pin to core 1 so it doesn't interrupt time-critical core 0 tasks
    xTaskCreatePinnedToCore(monitor_task, "monitor", 1536, NULL, 1, NULL, 1);
#endif
}

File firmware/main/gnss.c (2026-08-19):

#include "gnss.h"

#include <math.h>
#include <stdint.h>

#include "esp_log.h"
#include "status.h"
#include "uart.h"

static const char* TAG = "gnss";

// UBlox UART1 default configuration:
// TX:  38400 baud, 8 bits, no parity bit, 1 stop bit.
//      NMEA protocol with GGA, GLL, GSA, GSV, RMC, VTG, TXT messages are output
//      by default. UBX and RTCM 3.3 protocols are enabled by default but no
//      output messages are enabled by default
// RX:  38400 baud, 8 bits, no parity bit, 1 stop bit.
//      UBX, NMEA and RTCM 3.3 input protocols are enabled by default.
//      SPARTN input protocol is enabled by default.

// UBlox UART2 default configuration:
// TX:  38400 baud, 8 bits, no parity bit, 1 stop bit.
//      NMEA and UBX protocols are disabled by default.
//      RTCM 3.3 protocols is enabled by default but no output messages are
//      enabled by default
// RX:  38400 baud, 8 bits, no parity bit, 1 stop bit.
//      NMEA protocol is disabled by default.
//      UBX and RTCM 3.3 input protocols are enabled by default.
//      SPARTN input protocol is enabled by default.

// UBlox settings for diffrent GNSS Modes:
//                  Rover                               Base                PPP
// UART1    TX      UBX:NAV-PVT:out + NMEA:GGA:out      UBX:NAV-PVT:out     UBX:NAV-PVT:out
//          RX      UBX:Command:in                      UBX:Command:in      UBX:Command:in
//
// UART2    TX      none                                RTCM3:out           UBX:RAW:out
//          RX      RTCM3:in                            none                none

static void gnss_set_default_messages(void)
{
    ESP_LOGI(TAG, "Setting default GNSS messages");

    // UBlox UART1 TX
    // enable NMEA output to read GGA messages once every 10 epochs
    // some NMEA messages are enabled by default, so disable them
    uart1_send_command("CFG-VALSET 0 1 0 0 CFG-MSGOUT-NMEA_ID_GGA_UART1 10");
    uart1_send_command("CFG-VALSET 0 1 0 0 CFG-MSGOUT-NMEA_ID_GLL_UART1 0");
    uart1_send_command("CFG-VALSET 0 1 0 0 CFG-MSGOUT-NMEA_ID_GSA_UART1 0");
    uart1_send_command("CFG-VALSET 0 1 0 0 CFG-MSGOUT-NMEA_ID_GSV_UART1 0");
    uart1_send_command("CFG-VALSET 0 1 0 0 CFG-MSGOUT-NMEA_ID_RMC_UART1 0");
    uart1_send_command("CFG-VALSET 0 1 0 0 CFG-MSGOUT-NMEA_ID_VTG_UART1 0");
    uart1_send_command("CFG-VALSET 0 1 0 0 CFG-MSGOUT-NMEA_ID_TXT_UART1 0");
    uart1_send_command("CFG-VALSET 0 1 0 0 CFG-UART1OUTPROT-NMEA 1");
    // disable RTCM3 output
    uart1_send_command("CFG-VALSET 0 1 0 0 CFG-UART1OUTPROT-RTCM3X 0");
    // enable UBX output to read NAV-PVT messages
    uart1_send_command("CFG-VALSET 0 1 0 0 CFG-MSGOUT-UBX_NAV_PVT_UART1 1");
    uart1_send_command("CFG-VALSET 0 1 0 0 CFG-UART1OUTPROT-UBX 1");

    // UBlox UART1 RX
    // disable NMEA input
    uart1_send_command("CFG-VALSET 0 1 0 0 CFG-UART1INPROT-NMEA 0");
    // disable RTCM3 input
    uart1_send_command("CFG-VALSET 0 1 0 0 CFG-UART1INPROT-RTCM3X 0");
    // !!! MUST ALWAYS ENABLE UBX input to send commands to UBlox
    uart1_send_command("CFG-VALSET 0 1 0 0 CFG-UART1INPROT-UBX 1");

    // UBlox UART2 TX
    // disable NMEA output
    uart1_send_command("CFG-VALSET 0 1 0 0 CFG-UART2OUTPROT-NMEA 0");
    // disable RTCM3 output
    uart1_send_command("CFG-VALSET 0 1 0 0 CFG-UART2OUTPROT-RTCM3X 0");
    // disable UBX output
    uart1_send_command("CFG-VALSET 0 1 0 0 CFG-UART2OUTPROT-UBX 0");

    // UBlox UART2 RX
    // disable NMEA input
    uart1_send_command("CFG-VALSET 0 1 0 0 CFG-UART2INPROT-NMEA 0");
    // disable RTCM3 input
    uart1_send_command("CFG-VALSET 0 1 0 0 CFG-UART2INPROT-RTCM3X 0");
    // disable UBX input
    uart1_send_command("CFG-VALSET 0 1 0 0 CFG-UART2INPROT-UBX 0");
}

void gnss_set_mode_rover(void)
{
    gnss_set_default_messages();
    ESP_LOGI(TAG, "Setting GNSS mode to ROVER");

    // In Rover mode,
    // ESP32 reads GGA and NAV-PVT messages from UBlox UART1
    // ESP32 sends RTCM3 correction data to UBlox UART2

    // UBlox UART1 TX
    // already configured in gnss_set_default_messages()

    // UBlox UART2 TX
    // enable RTCM3 input to receive correction data from ESP32
    uart1_send_command("CFG-VALSET 0 1 0 0 CFG-UART2INPROT-RTCM3X 1");

    // Disable Survey-In mode
    uart1_send_command("CFG-VALSET 0 1 0 0 CFG-TMODE-MODE 0");

    status_set(STT_GNSS_MODE, GNSS_ROVER);
}

void gnss_set_mode_base(void)
{
    gnss_set_default_messages();
    ESP_LOGI(TAG, "Setting GNSS mode to BASE");

    // In Base mode,
    // ESP32 reads PVT messages from UBlox UART1, RTCM3 messages from UBlox UART2
    // ESP32 does not send any correction data to UBlox UART2.

    // UBlox UART1 TX
    // disable NMEA output, keep UBX output to read NAV-PVT messages
    uart1_send_command("CFG-VALSET 0 1 0 0 CFG-UART1OUTPROT-NMEA 0");

    // UBlox UART2 TX
    // enable RTCM3 output to send correction data to ESP32
    uart1_send_command("CFG-VALSET 0 1 0 0 CFG-MSGOUT-RTCM_3X_TYPE1005_UART2 1");
    uart1_send_command("CFG-VALSET 0 1 0 0 CFG-MSGOUT-RTCM_3X_TYPE1074_UART2 1");
    uart1_send_command("CFG-VALSET 0 1 0 0 CFG-MSGOUT-RTCM_3X_TYPE1077_UART2 1");
    uart1_send_command("CFG-VALSET 0 1 0 0 CFG-MSGOUT-RTCM_3X_TYPE1084_UART2 1");
    uart1_send_command("CFG-VALSET 0 1 0 0 CFG-MSGOUT-RTCM_3X_TYPE1087_UART2 1");
    uart1_send_command("CFG-VALSET 0 1 0 0 CFG-MSGOUT-RTCM_3X_TYPE1094_UART2 1");
    uart1_send_command("CFG-VALSET 0 1 0 0 CFG-MSGOUT-RTCM_3X_TYPE1097_UART2 1");
    uart1_send_command("CFG-VALSET 0 1 0 0 CFG-MSGOUT-RTCM_3X_TYPE1124_UART2 1");
    uart1_send_command("CFG-VALSET 0 1 0 0 CFG-MSGOUT-RTCM_3X_TYPE1127_UART2 1");
    uart1_send_command("CFG-VALSET 0 1 0 0 CFG-MSGOUT-RTCM_3X_TYPE1230_UART2 1");
    // uart1_send_command("CFG-VALSET 0 1 0 0 CFG-MSGOUT-RTCM_3X_TYPE4072_0_UART2 1");
    // uart1_send_command("CFG-VALSET 0 1 0 0 CFG-MSGOUT-RTCM_3X_TYPE4072_1_UART2 1");
    uart1_send_command("CFG-VALSET 0 1 0 0 CFG-UART2OUTPROT-RTCM3X 1");

    // Enable Fixed Base mode
    uart1_send_command("CFG-VALSET 0 1 0 0 CFG-TMODE-MODE 2");

    status_set(STT_GNSS_MODE, GNSS_BASE);
}

void gnss_set_mode_ppp(void)
{
    gnss_set_default_messages();
    ESP_LOGI(TAG, "Setting GNSS mode to PPP");

    // In PPP mode,
    // ESP32 reads PVT messages from UBlox UART1, RAW messages from UBlox UART2
    // ESP32 does not send any correction data to UBlox UART2.

    // UBlox UART1 TX
    // disable NMEA output, keep UBX output to read NAV-PVT messages
    uart1_send_command("CFG-VALSET 0 1 0 0 CFG-UART1OUTPROT-NMEA 0");

    // UBlox UART2 TX
    // enable UBX output to read RAW messages
    uart1_send_command("CFG-VALSET 0 1 0 0 CFG-MSGOUT-UBX_RXM_RAWX_UART2 1");
    uart1_send_command("CFG-VALSET 0 1 0 0 CFG-MSGOUT-UBX_RXM_SFRBX_UART2 1");
    uart1_send_command("CFG-VALSET 0 1 0 0 CFG-UART2OUTPROT-UBX 1");

    // Enable Survey-in Base Mode
    uart1_send_command("CFG-VALSET 0 1 0 0 CFG-TMODE-MODE 1");

    status_set(STT_GNSS_MODE, GNSS_PPP);
}
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

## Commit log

2025-11-25 Init KiCAD project with board shape
    [esp32s3-gnss-base-station.kicad_pcb, esp32s3-gnss-base-station.kicad_sch]
2025-12-12 Add KiCAD Schematic v0.1
    [esp32s3-gnss-base-station.kicad_pcb, esp32s3-gnss-base-station.kicad_sch]
2025-12-17 Add KicCAD PCB Layout v0.1 and order on JLCPCB
    [BOM-esp32s3-gnss-base-station.csv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]
2026-01-14 Update PCB and export some images
    [esp32s3-gnss-base-station.kicad_pcb, esp32s3-gnss-base-station.kicad_sch]
2026-07-23 Update Product images, and reference schematics
2026-07-23 Add documents for esp32-s3 and ublox zed-f9p
2026-08-12 Implement Config, Status and Battery Task
2026-08-13 Implement Ublox command, GNSS command, NMEA & UBX parser, UART1 reading
2026-08-16 Implement Server and UI webpage
    [partitions.csv]
2026-08-17 Implement GNSS Mode, get correct GNSS Height
    [gnss.c, parser.c, sdcard.h]
2026-08-17 Implement NTRIP Server to broadcast RTCM3 correction stream
    [logger.c, ntrip_server.c]
2026-08-19 Some fixes applied after field testing
    [gnss.c, main.c, ntrip_server.c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]
